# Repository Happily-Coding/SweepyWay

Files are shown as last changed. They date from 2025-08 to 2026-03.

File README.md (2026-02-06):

# SweepyWay Split Keyboard 

A truly ergonomic, begginner friendly keyboard.

<details open><summary><h2 style="display:inline-block">Photos & Outputs</h2></summary>

left side | right side
-|-
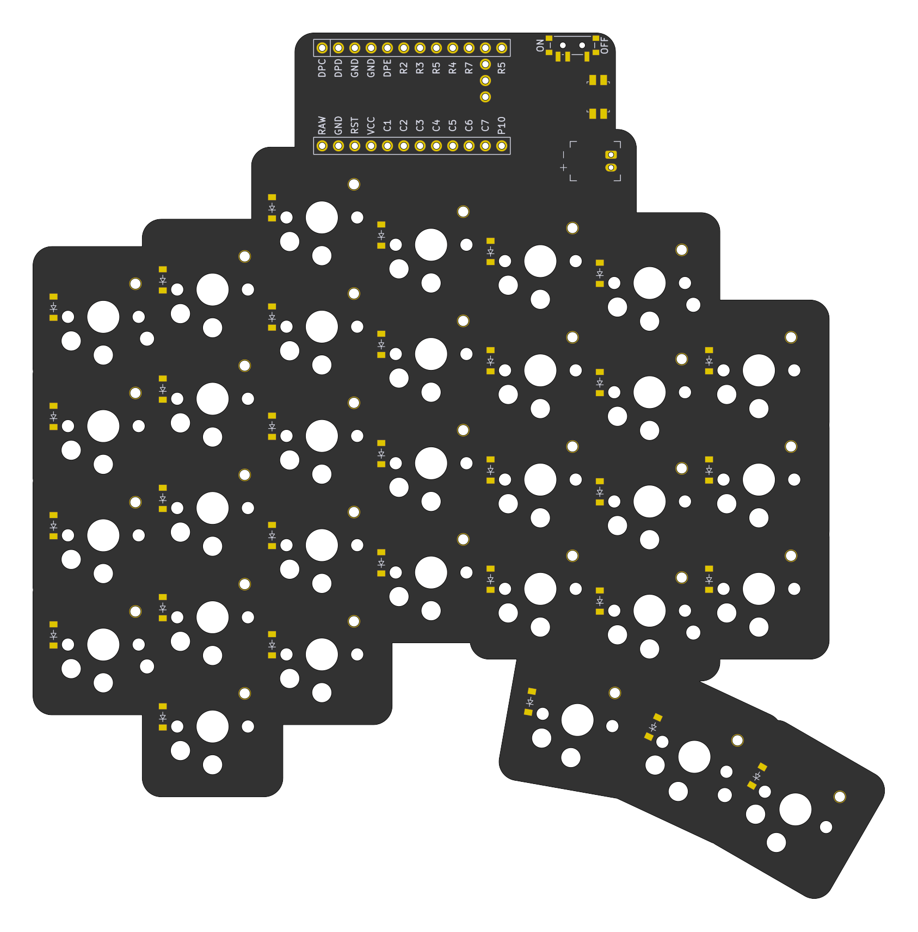
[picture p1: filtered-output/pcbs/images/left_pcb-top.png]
left
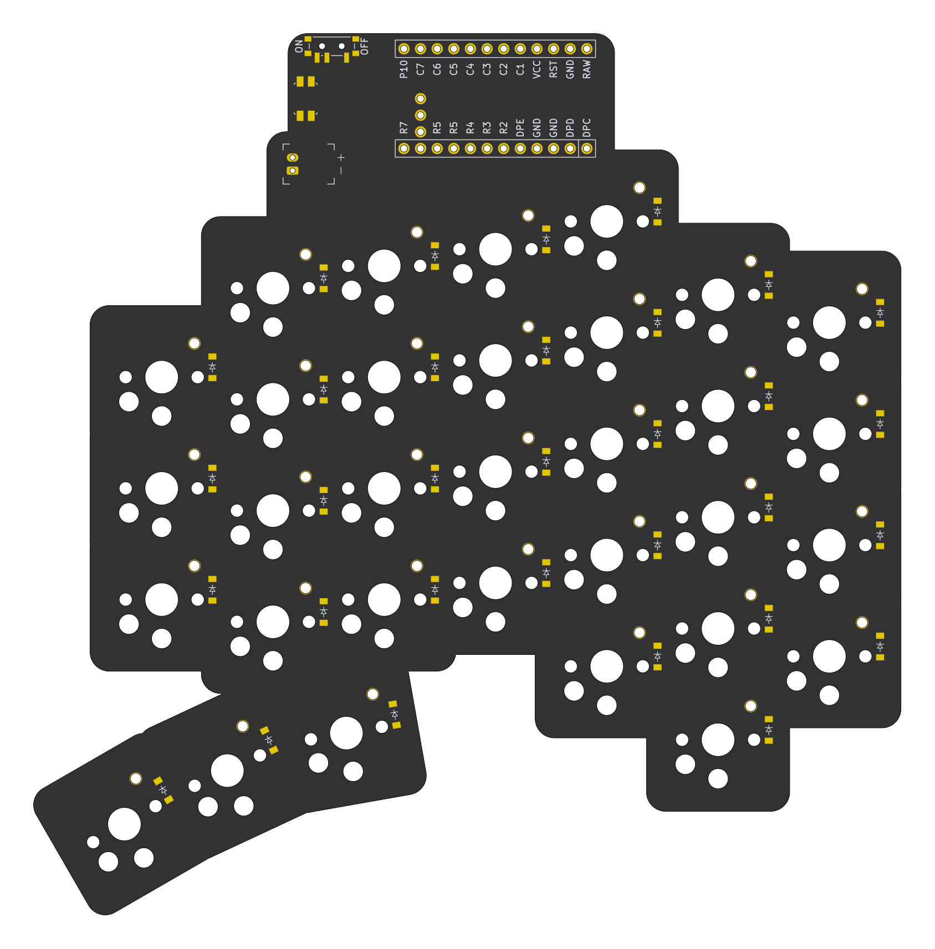
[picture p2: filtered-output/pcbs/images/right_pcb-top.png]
right
 | 

[More outputs](https://happily-coding.github.io/SweepyWay/filtered-output/) (images, pdfs, stl 3d models, etc)

<details><summary><h3 style="display:inline-block"> 3D Preview</h3></summary>

The 3D preview shows how the keyboard looks with all components in place (switches, diodes, MCU, and keycaps).

### 3D Model Files

#### Interactive 3D View (STL Format)
- [Left PCB STL](https://happily-coding.github.io/SweepyWay/filtered-output/pcbs/3d/left_pcb-3d.stl) 🎮
- [Right PCB STL](https://happily-coding.github.io/SweepyWay/filtered-output/pcbs/3d/right_pcb-3d.stl) 🎮

> 🎮 **How to View**: Click the links above, then GitHub will automatically render the STL files in an interactive 3D viewer. You can rotate, zoom, and pan using your mouse.

#### Markdown Rendering (ASCII STL)
The ASCII STL files are generated in the workflow and embedded in markdown using the ```stl code block syntax. GitHub renders these automatically when viewing the README.

> 💡 **Note**: The ASCII STL files are generated from the binary STL files in the workflow and embedded directly in this README for instant rendering.

#### STEP Files (CAD Exchange)
- [Left PCB STEP file](https://happily-coding.github.io/SweepyWay/filtered-output/pcbs/3d/left_pcb-3d.step) 🔧
- [Right PCB STEP file](https://happily-coding.github.io/SweepyWay/filtered-output/pcbs/3d/right_pcb-3d.step) 🔧

> ⚠️ **Note**: GitHub doesn't render STEP files directly. Use these for CAD software:
> - Download and open in KiCad 3D viewer, FreeCAD, Fusion 360, etc.
> - Use online STEP viewers like [3DViewer.net](https://3dviewer.net/)
> - Convert to STL format for GitHub rendering

### 3D Rendered Images

left side | right side
-|-
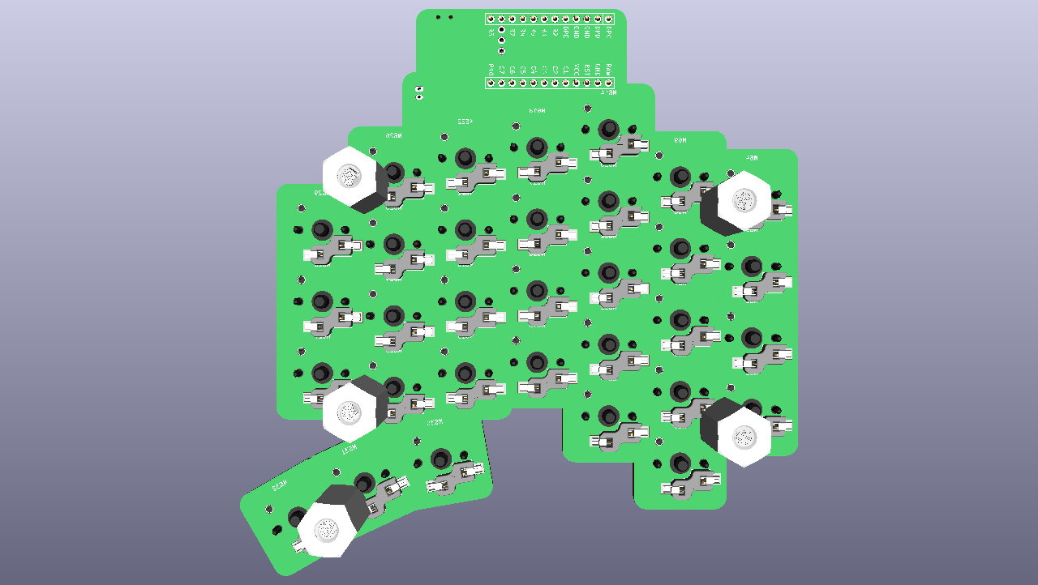
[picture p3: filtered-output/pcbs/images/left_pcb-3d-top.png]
left 3D top
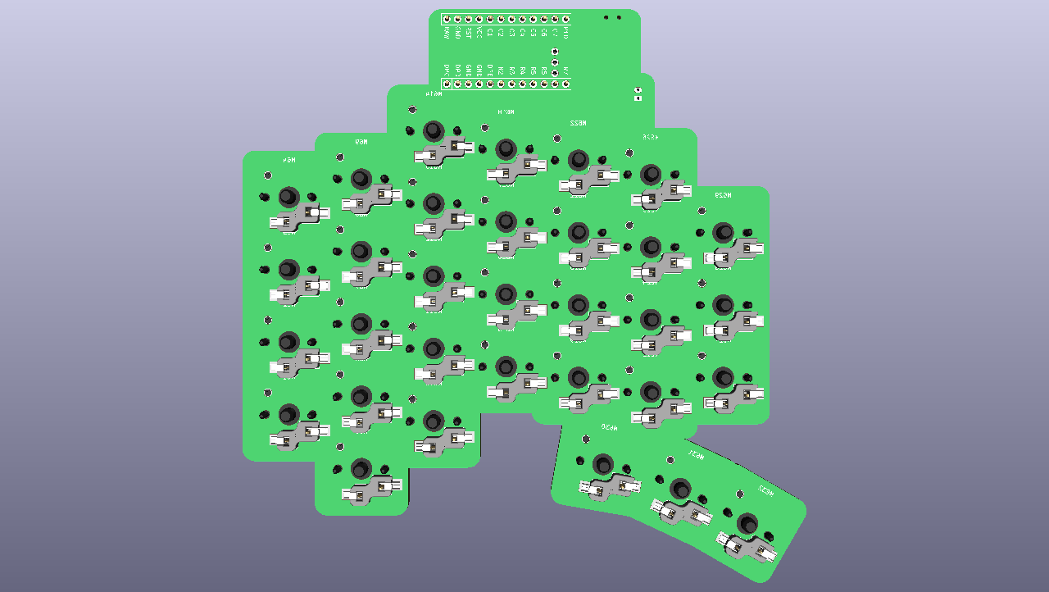
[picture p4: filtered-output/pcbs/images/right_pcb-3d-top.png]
right 3D top
 | 
left 3D bottom | right 3D bottom

### Troubleshooting Missing Components

If the 3D renders show only the PCB without components, the environment variables may not be properly set. The PCB files use `${PATH_TO_SWEEPYWAY_COMPONENT_MODELS}` but KiCad 9 also needs `KICAD9_3DMODEL_DIR`.

**Solution**: Set BOTH environment variables to the same path:
```bash
PATH_TO_SWEEPYWAY_COMPONENT_MODELS="/path/to/component_3d_models" \
KICAD9_3DMODEL_DIR="/path/to/component_3d_models" \
kibot -c kibot/3d_preview.kibot.yaml
```

**GitHub Actions**: The workflow now sets both variables to `${{ github.workspace }}/component_3d_models`

**Verification**: Check that:
1. `component_3d_models/` directory exists
2. All required STEP files are present: `Choc_V1_Hotswap.step`, `Choc_V1_Switch.step`, `Choc_V1_Keycap_MBK_White_1u.step`, etc.
3. The Docker container has access to the models directory

</details>

<details><summary><h3 style="display:inline-block"> Output details</h2></summary>
- Cases contains 3d models (not only of the case), l_cover is the plate that holds the switches firmly in place, and houses the controller and battery, protecting them
<!-- 
?v=1 was used to force the update of the cache from github (it could have been any parameter)
![left bottom](https://happily-coding.github.io/SweepyWay/images/left_pcb-bottom.png) | ![right bottom](https://happily-coding.github.io/SweepyWay/images/right_pcb-bottom.png)
-->
</details>

<details open><summary><h2 style="display:inline-block">Features</span></summary> 

* **Beginner friendly**
  * Available pdfs, so you can print the layout and see how it feels
  * Abundant keys, but in non disruptive places.
  * No soldering required (WIP)
* **Truly ergonomic**
  * Aggressive column stagger, like Ferris Sweep, to match how fingers are staggered.
  * Choc V1 keys
    * Very low actuation force switches available (example: nocturnal)
    * Low profile (seamless use without handrest, easier to adjust height without an adjustable desk)
    * ChocV1 spacing (reach the outer columns with less over-stretching)
  * Tenting, negative tilting, adjustable height and hand rest solutions (WIP)
* **Energy efficient**
  * [Nice!nano](https://nicekeyboards.com/nice-nano) optimised, but any promicro should work (bottom up) 
  <!-- * [Nice!view](https://nicekeyboards.com/nice-view) support Not tested, probably requires small modifications --> 
  * No leds
* **Accident prepared** 
  * Controller far away from accidental splash zones,
  * Power switch for transport
  * No metal plates to help prevent static discharge from friying the keyboard
  * Hotswappable battery, switches, keycaps, controller, and case. Replace anything that breaks or you dislike.
    * You can even remove the components and use them with a different pcb.
* **Easy to modify** (Declarative design done via yaml)
  * Layout is declared using [Ergogen](https://github.com/mrzealot/ergogen/). 
  * Uses Ergogen to translate YAML to a KiCad PCB and plate files for FR-4 fab or laser cutting
  * Uses Ergogen to output jscad files for the case, and openjscad to convert them to stl.
  * Uses [kicad-automation-scripts](https://github.com/productize/kicad-automation-scripts) and [FreeRouting](https://github.com/freerouting/freerouting) to **automatically route the traces on the PCB**
  * Uses [KiKit](https://github.com/yaqwsx/KiKit) to render PCB previews and production-ready **Gerber files**
  * Uses [Trimesh](https://github.com/mikedh/trimesh/tree/main) to parametrically create a palm rest for the keyboard shape.
  * Uses Kibot to produce jlpcb pos files and BOM so you can order your pcb assembled and not have to solder. (WIP) 
  * Compatible with [no solder spring headers](https://typeractive.xyz/products/no-solder-spring-headers) 

<details><summary><h2 style="display:inline-block"> Work in progress. TODO List</h2></summary>

- perfect top case, and replicate for right side
  - the controller area is delicate, we need to only increase height on the part that the controller and maybe the jsph and reset switch are, since otherwise they wont fit with the plate cutting into them
  - We need to keep the reset butotn exposed to the outside if we want to be able to use the keyboard flash with the cover on (which may be important for typing)
- add the battery and microcontroller 3d model to check there are no issues
- add a lengua in the wall of the case below the top plate to en sure no drainage on the corners?
- Add parametric tenting legs.
- Add spacing between case wall and pcb (add some more padding in addition to the wall thickness)
- Finish making hand rest parametric and integrate it into the pipeline
- Fix the additional outline to cover the controller
- make sure the bom & pos are outputed correctly and ideally automated
- Nice haves:
  - Make base tilting and tenting compatible and or adjustable height
  - add water draining holes
  - Add a piece of plastic that goes inward from the top of the border and fits in it to cover the pcb
  - add leds and spacing for a big batery in the tenting solution
  - add other controller types
  - improve controller pin assignment for better routing
  - Add headers soldering from jlpcb
  - add a tenting system with space for a larger batery or make space for a larger batery in the palm rest, so you can reasonably use the keyboard with rgb.
  - Add row staggered variants that are space efficient.
  - Make sure the keyboard is correctly produced with mbk spacing, and mx spacing.
  - Add the ability to customize keycap spacing for the outer columns and rows
</details>

<details><summary><h2 style="display:inline-block"> How to modify it</h2></summary>

### Setup
If you would like to modify this:
* fork it
* clone it locally with celoide submodule git clone --recurse-submodules https://github.com/Happily-Coding/SweepyWay.git
* change `ergogen/config.yaml` to your liking
* to test it locally if you have node, you can run npm npm i -g ergogen or just npm install from the directory of the repo.
* to be able to view the 3d models in kicad you need go to the top menu -> preferences -> path and add the value for PATH_TO_SWEEPYWAY_COMPONENT_MODELS, which should be the location of your 3d models folder for example C:\Users\YourName\KeyboardDesign\SweepyWay\component_3d_models. Then, after opening kicad , you can open the 3d viewer in the toolbar (or using alt 3).
* to be able to open individual step or stl files, i find [this page](https://3dviewer.net/index.html) comfortable
* to understand what each definition in ergogen ends up creating open the link to the repo [here ](https://ergogen.xyz/)
* reactivate github workflows
* reactivate github pages at https://github.com/your-name/your-repo/settings/pages, choose github actions instead of a branch
* push your changes; the `build.yml` GitHub Workflows(https://github.com/your-name/your-repo/actions) will pick it up, autoroute and generate Gerbers, all in a zip file, and then deploy it to github pages(https://your-name.github.io/your-repo/).
* or:
  * make sure to have Docker CLI and NodeJS installed
  * run `make setup clean all`
  * check the `output` folder for KiCad PCBs and Gerbers
* you can find the latest build artifacts [here](https://happily-coding.github.io/SweepyWay/)

See the [workflow](.github/workflows/build.yml) or the [Makefile](Makefile) for more details.

### Quickly previewing the pcb before pushing
Open the project, open a terminal, run ```cd ergogen``` and ```ergogen .```

### Quickly previewing the case and other jscad files before pushing
Open [neorama openjscad](https://neorama.de/) , and drag the jscad file to the button, you can pan and move using right click or shift rightclick.

### Quickly previewing the palmrest before pushing
- Install uv ```pip install uv``` and run uv sync to generate your virtual environment (only once)
- Run ergogen to produce the outlines.
- ```uv run palmrest_and_tenting_creation/create_palmrest.py```

<!-- 
### Add more keys in places that don't interfere with the controller
Add elements to the row or column matrix, and map them (WIP, TODO explain with more detail)

### Use other controllers

### Use mx switches / chocv2 switches

### Use other battery/reset switches/ footprints
See this examples: 
https://github.com/jsbursik/Janus-Keyboard mx nice nano reversible with custom footprints
https://github.com/tarneaux/triboard xiao controller choc spaced reversible with battery polygon!
https://github.com/Henkru/novum mx with jlpcb target, middle layer for stability, and awesome background art
https://github.com/Musab-Hassan/aurora_keyboard very detailed, and well organized mx example
https://github.com/soundmonster/samoklava/tree/main
https://github.com/christianselig/caldera-keyboard/blob/main/ergogen/config.yaml
https://github.com/jusdisgi/splaveferris/blob/main/ergogen/config.yaml (choc v1, smd) <-- reference for mirrored
https://github.com/jusdisgi/biggie-splays/blob/main/biggie-splays_choc_v1/config.yaml mirror matrix
https://pastebin.com/JzsmATYZ celoide reversible (obtianed from atreus/absolem discord) https://cdn.discordapp.com/attachments/759825860617437204/1376609916986327150/pleiades.yaml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
Complex case, and mounting example with celodie footpritns https://github.com/MalusKnight/SplitMax-Ergogen/blob/main/config.yaml and oleds
https://github.com/Nuclear-Squid/Quacken/blob/main/config.yaml [ro micro non celoide]
https://peterlyons.com/problog/2024/05/kipra-keyboard/ how to load an ergogen otuput to freecad 
https://github.com/johnlamb/LambBT/blob/main/ergogen/config.yaml case, m2 screwes, etc 
https://github.com/AtomicJon/jonkey/blob/main/jonkey-v2.yml other celoide footprints usage
https://github.com/scipioni/clavis alternative stup for auto routing 
#asym in theory can be used in outlines to get only mirrored or only normal points https://docs.ergogen.xyz/outlines/
-->
</details>

<details><summary><h2 style="display:inline-block"> Credits</h2></summary>

- [mxooaar](https://www.reddit.com/r/ErgoMechKeyboards/comments/1lanvon/comment/mxooaar/) for peaking my interest in actually building my idea for a keyboard
- [christianselig caldera keyboard](https://github.com/christianselig/caldera-keyboard) for showing that creating a custom keyboard is reasonably easy
- [Ergogen](https://github.com/ergogen/ergogen) for the awesome tool for building most of the keyboard
- [Soundmonster Samaklova Keyboard](https://github.com/soundmonster/samoklava/tree/main) for automatic electronic routing
- [tbaumann typematrix](https://github.com/tbaumann/typematrix_split_new/tree/main/ergogen) for automatic documentation, and example of how to use celoide ergonomic footprints
- [Celoide](https://github.com/ceoloide/ergogen-footprints) for the library of additional ergogen footprints for more parts and the awesome discord.
- [alakuu/skree](https://www.reddit.com/user/alakuu/) for taking the time to answer questions about pcb assembly services
- [Choco-rain](https://www.reddit.com/r/MechanicalKeyboards/comments/qanrr8/corne_with_3d_printed_cases_wrist_rests_and_plates/) for palmrest inspiration
</details>

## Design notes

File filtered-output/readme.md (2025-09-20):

Where create_palmrest produces its stl if ran locally.

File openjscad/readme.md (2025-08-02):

# Intro
The idea of using openjscad cli is to be able to convert openjscad files to stls.
This file lists the steps for local testing

# Build the image
- Build an image you can the run to perform the conversions
  - tag it as openjscad-cli so it's easily callable
  - Use the dockerfile located in openjscad
```
docker build -t openjscad-cli openjscad
```

# Run the image 
Run the image to convert all files in ergogen\output\cases to .stl

From a powershell cli at the project root:
```
docker run -it -v "${PWD}\ergogen\output\cases:/designs" openjscad-cli bash -c convert-all.sh
```

- -it: Keeps it interactive so you see output/errors
- -v "${PWD}\ergogen\output\cases:/designs" Mounts your local designs directory into the container
- openjscad-cli: The image you built and tagged
- overrides the entry point of the node image, instead executing the convert all script which on the workdir iterates through all the jscad files and outputs the stls

# Pcbway vs jlpcb vs seedfusion
Seedfusion is cheap for the microcontroller, but the assembly service is a bit expensive, and the 3d printing price is just insane

Pcbway could not autoprice my model, maybe try with an account since jlpcb didnt either without it
https://www.pcbway.com/rapid-prototyping/manufacture/?type=2&reffercode=TOP

JKOCB oyede srcear seeds studio xio ble pero sale 13.5o 12 usd de acuerdo a la cantidad. y no se si incluy shipping eso.
https://jlcpcb.com/user-center/smtPrivateLibrary/orderParts/?_t=1753498304483

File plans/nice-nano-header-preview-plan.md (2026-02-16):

# Nice!Nano Header Preview Footprint Plan

## Overview

Create a virtual footprint for displaying pin headers on the nice!nano controller in fabrication previews, POS files, and BOM - without adding any actual holes or pads to the PCB.

## Requirements

1. **Virtual Footprint**: No holes, pads, or silkscreen added to PCB
2. **3D Model**: Display header in 3D preview
3. **BOM Entry**: Include in bill of materials
4. **POS File Entry**: Include in pick-and-place file
5. **Two Headers**: One for left side, one for right side of nice!nano

## Technical Details

### Nice!Nano Dimensions (from mcu_nice_nano.js)

- Socket hole positions: X = -7.62 (left) and X = 7.62 (right)
- Row spacing: 2.54mm (standard pin header pitch)
- Number of pins per side: 12
- Y range: -12.7 to 15.24 (12 rows × 2.54mm)

### Available 3D Model

- `PinHeader_1x12_P2.54mm_Vertical.step` - Single row 12-pin vertical header
- Located in: `${PATH_TO_SWEEPYWAY_COMPONENT_MODELS}/`

### Header Positioning

The nice!nano in config.yaml is:
- Placed at `ref: mcu` 
- Rotated 90 degrees
- Has `reverse_mount: true` (MCU faces PCB)

For headers:
- Left header: positioned at the left pin row border
- Right header: positioned at the right pin row border
- Both headers should have the same rotation as the nice!nano (90 degrees)

## Implementation Plan

### Step 1: Create `header-preview_nano.js` Footprint

Create a new footprint file at:
```
ergogen/footprints/ceoloide/header-preview_nano.js
```

**Parameters:**
- `designator`: 'H' (Header)
- `side`: 'F' or 'B' (default: 'F')
- `include_silkscreen`: boolean (default: false)
- `pin_count`: number of pins (default: 12)
- `model_filename`: path to 3D model
- `model_xyz_offset`: [x, y, z] offset for 3D model positioning
- `model_xyz_rotation`: [x, y, z] rotation for 3D model
- `model_xyz_scale`: [x, y, z] scale for 3D model
- `supplier_link`: URL for BOM
- `manufacturer_part_number`: Part number for BOM
- `do_not_populate`: 'DNP' flag

**Key Features:**
- Uses `(attr exclude_from_pos_files exclude_from_bom)` is NOT set (we want it in POS/BOM)
- Or better: uses `(attr allow_soldermask_bridges)` like other preview footprints
- Includes 3D model reference
- Includes BOM properties

### Step 2: Add to config.yaml

Add two header preview entries in the `left_pcb` footprints section:

```yaml
# Left side header preview
header_left:
  what: ceoloide/header-preview_nano
  where:
    ref: mcu
  params:
    side: 'B'  # Same side as the nice_nano
    model_filename: "${PATH_TO_SWEEPYWAY_COMPONENT_MODELS}/PinHeader_1x12_P2.54mm_Vertical.step"
    model_xyz_offset: [-7.62, 0, 0]  # Offset to left pin row
    model_xyz_rotation: [0, 0, 0]  # Adjust for rotation
    supplier_link: 'https://www.digikey.com/en/products/detail/sullins-connector-solutions/PPTC121LFMS-RC/810154'
    manufacturer_part_number: 'PPTC121LFMS-RC'
    do_not_populate: 'DNP'

# Right side header preview  
header_right:
  what: ceoloide/header-preview_nano
  where:
    ref: mcu
  params:
    side: 'B'
    model_filename: "${PATH_TO_SWEEPYWAY_COMPONENT_MODELS}/PinHeader_1x12_P2.54mm_Vertical.step"
    model_xyz_offset: [7.62, 0, 0]  # Offset to right pin row
    model_xyz_rotation: [0, 0, 0]
    supplier_link: 'https://www.digikey.com/en/products/detail/sullins-connector-solutions/PPTC121LFMS-RC/810154'
    manufacturer_part_number: 'PPTC121LFMS-RC'
    do_not_populate: 'DNP'
```

### Step 3: Handle Rotation

The nice!nano is rotated 90 degrees in the config. The headers need to be positioned correctly:

- When MCU is rotated 90°, the X-axis becomes Y-axis and vice versa
- Headers should be placed at the correct offset relative to the MCU orientation
- The 3D model rotation may need adjustment to align properly

### Step 4: Duplicate for Right PCB

Add similar entries for `right_pcb` using `ref: mirror_mcu`.

## File Structure

```
ergogen/
├── footprints/
│   └── ceoloide/
│       ├── header-preview_nano.js  (NEW)
│       ├── standoff-preview.js     (reference)
│       └── hs-socket-fab-preview_choc_v1_v2.js  (reference)
└── config.yaml                      (MODIFY)
```

## Testing

1. Run ergogen to generate PCB files
2. Open in KiCad and verify:
   - Headers appear in 3D viewer
   - Headers are positioned correctly on nice!nano borders
   - Headers appear in BOM export
   - Headers appear in POS file

## Notes

- The `do_not_populate: 'DNP'` flag indicates these should not be auto-placed by the manufacturer
- Headers are typically hand-soldered after the MCU is installed
- The Z-offset may need adjustment based on actual header height

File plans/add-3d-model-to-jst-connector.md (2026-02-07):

# Add 3D Model Support to battery_connector_jst_ph_2 Footprint

## Overview

This plan outlines the steps to add 3D model support to the [`battery_connector_jst_ph_2.js`](../ergogen/footprints/ceoloide/battery_connector_jst_ph_2.js) footprint, following the same pattern used in other footprints like [`diode_tht_sod123.js`](../ergogen/footprints/ceoloide/diode_tht_sod123.js) and [`switch_choc_v1_v2.js`](../ergogen/footprints/ceoloide/switch_choc_v1_v2.js).

## Current Status

- **Footprint File**: [`ergogen/footprints/ceoloide/battery_connector_jst_ph_2.js`](../ergogen/footprints/ceoloide/battery_connector_jst_ph_2.js)
- **3D Model Support**: ❌ No - Not Configured
- **Available 3D Models**: ✅ Yes - Files already exist in [`component_3d_models/`](../component_3d_models/):
  - `JSTPH2 S2B-PH-K-S(LF)(SN).STEP`
  - `JSTPH2 S2B-PH-K-S(LF)(SN).wrl`

## Pattern Analysis

Based on analysis of other footprints, the 3D model implementation follows this pattern:

### 1. Parameters Section
Add four parameters to the `params` object:
- `<component>_3dmodel_filename`: Path to STEP/WRL file (default: '')
- `<component>_3dmodel_xyz_offset`: [x, y, z] offset in mm (default: [0, 0, 0])
- `<component>_3dmodel_xyz_scale`: [x, y, z] scale factors (default: [1, 1, 1])
- `<component>_3dmodel_xyz_rotation`: [x, y, z] rotation in degrees (default: [0, 0, 0])

### 2. Template String
Create a template string constant that generates the KiCad 3D model entry.

### 3. Conditional Inclusion
Add a conditional check before the footprint closing parenthesis to include the 3D model only if a filename is provided.

### 4. Documentation
Add parameter documentation in the comments section.

## Implementation Steps

### Step 1: Add Parameter Documentation

Add the following documentation after line 41 (after `include_courtyard` parameter description):

```javascript
//    connector_3dmodel_filename: default is ''
//      Allows you to specify the path to a 3D model STEP or WRL file to be
//      used when rendering the PCB. Use the ${VAR_NAME} syntax to point to
//      a KiCad configured path.
//    connector_3dmodel_xyz_offset: default is [0, 0, 0]
//      xyz offset (in mm), used to adjust the position of the 3d model
//      relative the footprint.
//    connector_3dmodel_xyz_scale: default is [1, 1, 1]
//      xyz scale, used to adjust the size of the 3d model relative to its
//      original size.
//    connector_3dmodel_xyz_rotation: default is [0, 0, 0]
//      xyz rotation (in degrees), used to adjust the orientation of the 3d
//      model relative the footprint.
```

### Step 2: Add Parameters to params Object

Add the following parameters to the `params` object after line 52 (after `BAT_N` parameter):

```javascript
    connector_3dmodel_filename: '',
    connector_3dmodel_xyz_offset: [0, 0, 0],
    connector_3dmodel_xyz_scale: [1, 1, 1],
    connector_3dmodel_xyz_rotation: [0, 0, 0],
```

### Step 3: Add 3D Model Template String

Add the following template string constant after line 282 (after `reversible_traces` constant):

```javascript
    const connector_3dmodel = `
        (model ${p.connector_3dmodel_filename}
            (offset (xyz ${p.connector_3dmodel_xyz_offset[0]} ${p.connector_3dmodel_xyz_offset[1]} ${p.connector_3dmodel_xyz_offset[2]}))
            (scale (xyz ${p.connector_3dmodel_xyz_scale[0]} ${p.connector_3dmodel_xyz_scale[1]} ${p.connector_3dmodel_xyz_scale[2]}))
            (rotate (xyz ${p.connector_3dmodel_xyz_rotation[0]} ${p.connector_3dmodel_xyz_rotation[1]} ${p.connector_3dmodel_xyz_rotation[2]}))
        )
        `
```

### Step 4: Add Conditional Inclusion

Modify the code after line 325 (after `final += standard_closing;`) to add conditional inclusion:

```javascript
    final += standard_closing;
    
    if (p.connector_3dmodel_filename) {
      final += connector_3dmodel
    }
    
    if (p.reversible && p.include_traces) {
      final += reversible_traces;
    }
```

**Note**: The 3D model should be added inside the footprint before the closing parenthesis, so we need to add it BEFORE `standard_closing`, not after. Let me correct this:

### Step 4 (Corrected): Add Conditional Inclusion

Modify the code around line 325 to add conditional inclusion BEFORE `standard_closing`:

```javascript
    if (p.reversible) {
      final += reversible_pads;
    } else if (p.side == "F") {
      final += front_pads;
    } else if (p.side == "B") {
      final += back_pads;
    }
    
    if (p.connector_3dmodel_filename) {
      final += connector_3dmodel
    }
    
    final += standard_closing;
    if (p.reversible && p.include_traces) {
      final += reversible_traces;
    }
```

## Expected Result

After implementation, the footprint will support 3D models that can be configured in [`ergogen/config.yaml`](../ergogen/config.yaml) like this:

```yaml
pads_bat:
  what: ceoloide/battery_connector_jst_ph_2
  params:
    connector_3dmodel_filename: "${PATH_TO_SWEEPYWAY_COMPONENT_MODELS}/JSTPH2 S2B-PH-K-S(LF)(SN).wrl"
    connector_3dmodel_xyz_offset: [0, 0, 0]
    connector_3dmodel_xyz_scale: [1, 1, 1]
    connector_3dmodel_xyz_rotation: [0, 0, 0]
  where:
    ref: mcu
    shift: [mcu_x/2 +22, -10]
    rotate: 270
```

## Testing Checklist

After implementation:

- [ ] Verify the modified footprint file has correct syntax
- [ ] Run `ergogen .` in the `ergogen` directory to regenerate PCB files
- [ ] Open the generated KiCad files
- [ ] Use the 3D viewer (Alt+3) to verify the model appears correctly
- [ ] Check that the connector model is properly positioned and oriented
- [ ] Verify no errors in KiCad console
- [ ] Test with both STEP and WRL formats
- [ ] Test with reversible and non-reversible configurations

## Notes

1. **Parameter Naming**: Using `connector_3dmodel_*` prefix to be consistent with the component type and avoid conflicts with other parameters.

2. **Model Format**: KiCad supports both STEP (.step, .stp) and WRL (.wrl) formats. WRL is typically preferred for KiCad 3D viewer performance.

3. **Offset and Rotation**: The default values (0, 0, 0) may need adjustment based on the actual 3D model's origin and orientation. Users can fine-tune these values in their config.yaml.

4. **Reversible Footprints**: For reversible footprints, the 3D model should only appear once (not duplicated on both sides) since the component is only mounted on one side.

5. **Existing Models**: The 3D model files already exist in the project at:
   - [`component_3d_models/JSTPH2 S2B-PH-K-S(LF)(SN).STEP`](../component_3d_models/JSTPH2%20S2B-PH-K-S(LF)(SN).STEP)
   - [`component_3d_models/JSTPH2 S2B-PH-K-S(LF)(SN).wrl`](../component_3d_models/JSTPH2%20S2B-PH-K-S(LF)(SN).wrl)

## References

- Similar implementation in [`diode_tht_sod123.js`](../ergogen/footprints/ceoloide/diode_tht_sod123.js:24-36, 55-58, 102-107, 124-126)
- Similar implementation in [`switch_choc_v1_v2.js`](../ergogen/footprints/ceoloide/switch_choc_v1_v2.js:79-117, 180-191, 453-475, 535-541)
- JST PH 2.0mm connector datasheet: https://cdn.shopify.com/s/files/1/0618/5674/3655/files/JST-S2B-PH-K.pdf?v=1670451309
- 3D model source: https://www.snapeda.com/parts/S2B-PH-K-S(LF)(SN)/JST/view-part/

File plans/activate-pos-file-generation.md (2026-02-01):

# Plan: Activate POS File Generation in GitHub Actions

## Current State

### What's Already Implemented

1. **POS File Generation** (`.github/workflows/build.yaml:73-77`)
   - KiBot generates POS files using `jlpcb_pos.kibot.yaml` configuration
   - Files are output to `ergogen/output/pos/` directory
   - Separate files for front and back sides

2. **Post-Processing Script** (`kibot/fix_pos_package_name.py`)
   - Replaces footprint names with JLCPCB part numbers
   - Maps `switch_choc_v1_v2` → `CPG135001S30`
   - Already tested and working (verified in `manualboms/manualpos 2026-02-01/`)

3. **KiBot Configuration** (`kibot/jlpcb_pos.kibot.yaml`)
   - Generates ASCII format position files
   - Units in millimeters
   - Separate files for front and back
   - Only SMD components (hotswap sockets are SMD)

### What's Missing

The GitHub Actions workflow does **not**:
1. Run the post-processing script on generated POS files
2. Copy the processed POS files to `filtered-output` directory for deployment

## Required Changes

### 1. Add Post-Processing Step to Workflow

Add a new step after the POS file generation (after line 77 in `.github/workflows/build.yaml`):

```yaml
- name: Post-process POS files for JLCPCB
  run: |
    for board in left_pcb right_pcb; do
      for side in bottom top; do
        input_file="ergogen/output/pos/${board}/${board}-${side}.pos"
        if [ -f "$input_file" ]; then
          python kibot/fix_pos_package_name.py "$input_file" "${input_file}-jlcpcb.pos"
        fi
      done
    done
```

### 2. Copy Processed POS Files to filtered-output

Add a step after the post-processing step:

```yaml
- name: Copy processed POS files to filtered-output
  run: |
    mkdir -p filtered-output/pos
    for board in left_pcb right_pcb; do
      for side in bottom top; do
        if [ -f "ergogen/output/pos/${board}/${board}-${side}-jlcpcb.pos" ]; then
          cp "ergogen/output/pos/${board}/${board}-${side}-jlcpcb.pos" "filtered-output/pos/"
        fi
      done
    done
```

### 3. Update Existing "Make filtered output" Step

The existing step (lines 70-72) already copies `ergogen/output/` to `filtered-output/`, but it excludes `fp-info-cache`. We need to ensure POS files are included.

Current step:
```yaml
- name: Make filtered output (excluding fp-info-cache) 1
  run: |
    rsync -a --exclude='fp-info-cache' ergogen/output/ filtered-output/
```

This should already include POS files, but we should verify the directory structure is correct.

## Expected Output Structure

After activation, the `filtered-output/` directory will contain:

```
filtered-output/
├── pos/
│   ├── left_pcb-bottom-jlcpcb.pos
│   ├── left_pcb-top-jlcpcb.pos
│   ├── right_pcb-bottom-jlcpcb.pos
│   └── right_pcb-top-jlcpcb.pos
├── gerbers/
├── images/
└── cases/
```

## POS File Format

The processed POS files will have the format:

```
### Footprint positions - created on <timestamp> ###
### Printed by KiCad version 9.0.2
## Unit = mm, Angle = deg.
## Side : bottom
# Ref     Val       Package                 PosX       PosY       Rot  Side
S1                  CPG135001S30            35.0000  -133.0000  180.0000  bottom
S2                  CPG135001S30            35.0000  -116.0000  180.0000  bottom
...
## End
```

## Workflow Changes

Here's the complete workflow section that needs modification:

```yaml
# ... existing steps ...

- name: Run KiBot to generate jlpcb pos
  uses: ./.github/actions/kibot
  with:
    boards: left_pcb right_pcb
    config: jlpcb_pos

- name: Post-process POS files for JLCPCB
  run: |
    for board in left_pcb right_pcb; do
      for side in bottom top; do
        input_file="ergogen/output/pos/${board}/${board}-${side}.pos"
        if [ -f "$input_file" ]; then
          python kibot/fix_pos_package_name.py "$input_file" "${input_file}-jlcpcb.pos"
        fi
      done
    done

- name: Copy processed POS files to filtered-output
  run: |
    mkdir -p filtered-output/pos
    for board in left_pcb right_pcb; do
      for side in bottom top; do
        if [ -f "ergogen/output/pos/${board}/${board}-${side}-jlcpcb.pos" ]; then
          cp "ergogen/output/pos/${board}/${board}-${side}-jlcpcb.pos" "filtered-output/pos/"
        fi
      done
    done

- name: Run KiBot to generate jlpcb bom
  uses: ./.github/actions/kibot
  with:
    boards: left_pcb right_pcb
    config: jlpcb_bom

# ... rest of workflow ...
```

## Benefits

1. **Automated JLCPCB Assembly**: POS files with correct part numbers will be automatically generated
2. **No Manual Steps**: Eliminates the need to manually run the post-processing script
3. **Consistent Output**: Every build will have the same POS file format
4. **Version Control**: POS files are tracked in the build artifacts
5. **Easy Deployment**: Files are automatically deployed to GitHub Pages

## Testing

After implementing the changes:

1. Trigger a workflow run (either by pushing to main or using workflow_dispatch)
2. Check the workflow logs to ensure:
   - POS files are generated by KiBot
   - Post-processing script runs successfully
   - Files are copied to filtered-output
3. Download the build artifacts
4. Verify POS files contain `CPG135001S30` instead of `switch_choc_v1_v2`

## Notes

- The post-processing script is idempotent (can be run multiple times safely)
- If a POS file doesn't exist (e.g., no components on that side), the script will skip it gracefully
- The `-jlcpcb.pos` suffix distinguishes processed files from raw POS files
- Both raw and processed files are preserved for debugging purposes

## Related Files

- `.github/workflows/build.yaml` - Main workflow file to modify
- `kibot/jlpcb_pos.kibot.yaml` - POS file generation configuration (already complete)
- `kibot/fix_pos_package_name.py` - Post-processing script (already complete)
- `ergogen/footprints/ceoloide/switch_choc_v1_v2.js` - Switch footprint with include_in_pos_files parameter
- `ergogen/config.yaml` - Config with include_in_pos_files: true for switches

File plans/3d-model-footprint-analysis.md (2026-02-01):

# 3D Model Footprint Analysis for SweepyWay Keyboard

## Executive Summary

This document analyzes the footprint configurations for the controller, power switch, SMD diodes, reset switch, and JST PH connector in the SweepyWay keyboard project. It identifies which footprints currently support 3D models, which don't, and provides recommendations for adding 3D model support.

**Note:** Reset switch and JST PH connector 3D model implementation is deferred for now.

## Current Status Overview

### 1. Controller (Nice!Nano V2)

**Footprint File:** [`ergogen/footprints/ceoloide/mcu_nice_nano.js`](../ergogen/footprints/ceoloide/mcu_nice_nano.js)

**3D Model Support:** ✅ **YES - Already Configured**

**Parameters Available:**
- `mcu_3dmodel_filename`: Path to STEP/WRL file
- `mcu_3dmodel_xyz_offset`: [x, y, z] offset in mm
- `mcu_3dmodel_xyz_scale`: [x, y, z] scale factors
- `mcu_3dmodel_xyz_rotation`: [x, y, z] rotation in degrees

**Current Usage in config.yaml:**
```yaml
promicro:
  what: ceoloide/mcu_nice_nano
  params:
    reverse_mount: true
    include_extra_pins: true
    # Pin assignments...
```

**Status:** The footprint supports 3D models but the parameters are not currently set in [`config.yaml`](../ergogen/config.yaml:805-844).

**Available 3D Model:**
- File exists: [`component_3d_models/Nice_Nano_V2.step`](../component_3d_models/Nice_Nano_V2.step)
- Source: https://github.com/infused-kim/kb_ergogen_fp/tree/main/3d_models

**Recommendation:** ✅ **EASY TO CONFIGURE** - Add the 3D model parameters to the config.yaml file.

---

### 2. Power Switch (Alps SSSS811101)

**Footprint File:** [`ergogen/footprints/ceoloide/power_switch_smd_side.js`](../ergogen/footprints/ceoloide/power_switch_smd_side.js)

**3D Model Support:** ✅ **YES - Already Configured**

**Parameters Available:**
- `switch_3dmodel_filename`: Path to STEP/WRL file
- `switch_3dmodel_xyz_offset`: [x, y, z] offset in mm
- `switch_3dmodel_xyz_scale`: [x, y, z] scale factors
- `switch_3dmodel_xyz_rotation`: [x, y, z] rotation in degrees

**Current Usage in config.yaml:**
```yaml
power:
  what: ceoloide/power_switch_smd_side
  params:
    side: F
  adjust:
    rotate: 90
  where:
    ref: mcu
    shift: [mcu_x/2 +16, 8]
```

**Status:** The footprint supports 3D models but the parameters are not currently set in [`config.yaml`](../ergogen/config.yaml:863-873).

**Available 3D Model Sources:**
- UltraLibrarian: https://app.ultralibrarian.com/details/877b6255-2882-11e9-ab3a-0a3560a4cccc/Alps-Electric/SSSS811101
- SnapEDA: https://www.snapeda.com/parts/SSSS811101/ALPS/view-part/
- Datasheet: https://cdn.shopify.com/s/files/1/0618/5674/3655/files/ALPS-SSSS811101.pdf?v=1670451309

**Recommendation:** ✅ **EASY TO CONFIGURE** - Download a 3D model and add the parameters to config.yaml.

---

### 3. SMD Diode (SOD-123 Package - 1N4148W)

**Footprint File:** [`ergogen/footprints/ceoloide/diode_tht_sod123.js`](../ergogen/footprints/ceoloide/diode_tht_sod123.js)

**3D Model Support:** ✅ **YES - Already Configured**

**Parameters Available:**
- `diode_3dmodel_filename`: Path to STEP/WRL file
- `diode_3dmodel_xyz_offset`: [x, y, z] offset in mm
- `diode_3dmodel_xyz_scale`: [x, y, z] scale factors
- `diode_3dmodel_xyz_rotation`: [x, y, z] rotation in degrees

**Current Usage in config.yaml:**
```yaml
diode:
  what: ceoloide/diode_tht_sod123
  where:
    - leftkey
  params:
    from: "{{colrow}}"
    to: "{{row_net}}"
    side: F
    include_tht: false
    reversible: false
  adjust:
    shift: [horizontal_diode_shift,vertical_diode_shift]
    rotate: 90 + diode_rotation
```

**Status:** The footprint supports 3D models but the parameters are not currently set in [`config.yaml`](../ergogen/config.yaml:791-803).

**Available 3D Model Sources:**
- UltraLibrarian: Search for "SOD-123" or "1N4148W"
- SnapEDA: https://www.snapeda.com/ (search for 1N4148W)
- Datasheet: https://cdn.shopify.com/s/files/1/0618/5674/3655/files/Semtech-1N4148W.pdf?v=1670451309
- KiCad library: Many KiCad installations include SOD-123 3D models in the default libraries

**Recommendation:** ✅ **EASY TO CONFIGURE** - Download a 3D model and add the parameters to config.yaml.

**Note:** Since there are multiple diodes in the keyboard (one per key), adding 3D models for all of them may significantly increase the file size and rendering time. Consider whether you need 3D models for all diodes or just a representative sample.

---

### 4. Reset Switch (Panasonic EVQ-PU[A|C|J|L]02K) ⏸️ **DEFERRED**

**Footprint File:** [`ergogen/footprints/ceoloide/reset_switch_smd_side.js`](../ergogen/footprints/ceoloide/reset_switch_smd_side.js)

**3D Model Support:** ❌ **NO - Not Configured**

**Parameters Available:** None

**Current Usage in config.yaml:**
```yaml
reset:
  what: ceoloide/reset_switch_smd_side
  params:
    side: F
    from: GND
    to: RST
  adjust:
    rotate: 270
  where:
    ref: mcu
    shift: [mcu_x/2 +18 +2, -0]
```

**Status:** The footprint does NOT have 3D model parameters. The code would need to be modified.

**Available 3D Model Sources:**
- SnapEDA: https://www.snapeda.com/parts/EVQ-PUC02K/Panasonic/view-part/
- UltraLibrarian: https://app.ultralibrarian.com/details/a0479524-2b3d-11ea-a124-0ad2c9526b44/Panasonic/EVQ-PUJ02K
- Datasheet: https://cdn.shopify.com/s/files/1/0618/5674/3655/files/PANASONIC-EVQPUC02K.pdf?v=1670451309

**Recommendation:** ⚠️ **REQUIRES CODE MODIFICATION** - Add 3D model parameters to the footprint file following the pattern used in power_switch_smd_side.js.

---

### 5. JST PH 2-Pin Battery Connector ⏸️ **DEFERRED**

**Footprint File:** [`ergogen/footprints/ceoloide/battery_connector_jst_ph_2.js`](../ergogen/footprints/ceoloide/battery_connector_jst_ph_2.js)

**3D Model Support:** ❌ **NO - Not Configured**

**Parameters Available:** None

**Current Usage in config.yaml:**
```yaml
pads_bat:
  what: ceoloide/battery_connector_jst_ph_2
  params:
  where:
    ref: mcu
    shift: [mcu_x/2 +22, -10]
    rotate: 270
```

**Status:** The footprint does NOT have 3D model parameters. The code would need to be modified.

**Available 3D Model Sources:**
- JST official website may have CAD models
- SnapEDA typically has JST connector models
- Datasheet: https://cdn.shopify.com/s/files/1/0618/5674/3655/files/JST-S2B-PH-K.pdf?v=1670451309

**Recommendation:** ⚠️ **REQUIRES CODE MODIFICATION** - Add 3D model parameters to the footprint file.

---

## Summary Table

| Component | Footprint Has 3D Support? | Configured in YAML? | Action Required | Priority |
|---|---|---|---|---|
| Nice!Nano V2 Controller | ✅ Yes | ❌ No | Add parameters to config.yaml | High |
| Power Switch (SSSS811101) | ✅ Yes | ❌ No | Add parameters to config.yaml | High |
| SMD Diode (SOD-123) | ✅ Yes | ❌ No | Add parameters to config.yaml | Medium |
| Reset Switch (EVQ-PU02K) | ❌ No | N/A | Modify footprint file | ⏸️ Deferred |
| JST PH Connector | ❌ No | N/A | Modify footprint file | ⏸️ Deferred |

---

## Implementation Plan

### Phase 1: Easy Wins (No Code Changes) - Current Focus

These components have 3D model support built into their footprints and only need configuration in config.yaml.

#### 1.1 Configure Nice!Nano V2 3D Model

Add to [`config.yaml`](../ergogen/config.yaml:805-844) in the `promicro` section:

```yaml
promicro:
  what: ceoloide/mcu_nice_nano
  params:
    reverse_mount: true
    include_extra_pins: true
    mcu_3dmodel_filename: "${PATH_TO_SWEEPYWAY_COMPONENT_MODELS}/Nice_Nano_V2.step"
    mcu_3dmodel_xyz_offset: [0, 0, 0]
    mcu_3dmodel_xyz_scale: [1, 1, 1]
    mcu_3dmodel_xyz_rotation: [0, 0, 0]
    # ... rest of pin assignments
```

#### 1.2 Configure Power Switch 3D Model

First, download a 3D model from one of the sources above and save it to [`component_3d_models/`](../component_3d_models/).

Then add to [`config.yaml`](../ergogen/config.yaml:863-873) in the `power` section:

```yaml
power:
  what: ceoloide/power_switch_smd_side
  params:
    side: F
    switch_3dmodel_filename: "${PATH_TO_SWEEPYWAY_COMPONENT_MODELS}/Alps_SSSS811101.step"
    switch_3dmodel_xyz_offset: [0, 0, 0]
    switch_3dmodel_xyz_scale: [1, 1, 1]
    switch_3dmodel_xyz_rotation: [0, 0, 0]
  adjust:
    rotate: 90
  where:
    ref: mcu
    shift: [mcu_x/2 +16, 8]
```

#### 1.3 Configure SMD Diode 3D Model

First, download a 3D model from one of the sources above and save it to [`component_3d_models/`](../component_3d_models/).

Then add to [`config.yaml`](../ergogen/config.yaml:791-803) in the `diode` section:

```yaml
diode:
  what: ceoloide/diode_tht_sod123
  where:
    - leftkey
  params:
    from: "{{colrow}}"
    to: "{{row_net}}"
    side: F
    include_tht: false
    reversible: false
    diode_3dmodel_filename: "${PATH_TO_SWEEPYWAY_COMPONENT_MODELS}/SOD123_1N4148W.step"
    diode_3dmodel_xyz_offset: [0, 0, 0]
    diode_3dmodel_xyz_scale: [1, 1, 1]
    diode_3dmodel_xyz_rotation: [0, 0, 0]
  adjust:
    shift: [horizontal_diode_shift,vertical_diode_shift]
    rotate: 90 + diode_rotation
```

**Important Note:** The SweepyWay keyboard has multiple diodes (one per key). Adding 3D models for all diodes will:
- Increase the KiCad file size significantly
- Slow down 3D rendering in KiCad
- May not provide much additional value since diodes are small and uniform

**Recommendation:** Consider starting with just a few diodes to test, or skip diode 3D models entirely if they don't add significant value to your design verification process.

### Phase 2: Deferred - Code Modifications Required ⏸️

The following components require code modifications to their footprint files. Implementation is deferred for now.

#### 2.1 Add 3D Model Support to Reset Switch Footprint

Modify [`ergogen/footprints/ceoloide/reset_switch_smd_side.js`](../ergogen/footprints/ceoloide/reset_switch_smd_side.js):

1. Add parameters to the `params` object (around line 34):
```javascript
module.exports = {
  params: {
    designator: 'RST',
    side: 'F',
    reversible: false,
    include_bosses: false,
    include_silkscreen: true,
    include_courtyard: false,
    switch_3dmodel_filename: '',
    switch_3dmodel_xyz_offset: [0, 0, 0],
    switch_3dmodel_xyz_rotation: [0, 0, 0],
    switch_3dmodel_xyz_scale: [1, 1, 1],
    from: { type: 'net', value: 'GND' },
    to: { type: 'net', value: 'RST' },
  },
```

2. Add 3D model generation code before the `common_end` (around line 107):
```javascript
    const switch_3dmodel = `
    (model ${p.switch_3dmodel_filename}
      (offset (xyz ${p.switch_3dmodel_xyz_offset[0]} ${p.switch_3dmodel_xyz_offset[1]} ${p.switch_3dmodel_xyz_offset[2]}))
      (scale (xyz ${p.switch_3dmodel_xyz_scale[0]} ${p.switch_3dmodel_xyz_scale[1]} ${p.switch_3dmodel_xyz_scale[2]}))
      (rotate (xyz ${p.switch_3dmodel_xyz_rotation[0]} ${p.switch_3dmodel_xyz_rotation[1]} ${p.switch_3dmodel_xyz_rotation[2]}))
    )
    `
```

3. Add conditional inclusion before `common_end` (around line 132):
```javascript
    if (p.switch_3dmodel_filename) {
      final += switch_3dmodel
    }

    final += common_end;
```

4. Update config.yaml to use the new parameters (similar to power switch).

#### 2.2 Add 3D Model Support to JST PH Connector Footprint

Modify [`ergogen/footprints/ceoloide/battery_connector_jst_ph_2.js`](../ergogen/footprints/ceoloide/battery_connector_jst_ph_2.js):

1. Add parameters to the `params` object (around line 43):
```javascript
module.exports = {
  params: {
    designator: 'JST',
    side: 'F',
    reversible: false,
    include_traces: true,
    trace_width: 0.250,
    include_silkscreen: true,
    include_fabrication: true,
    include_courtyard: true,
    connector_3dmodel_filename: '',
    connector_3dmodel_xyz_offset: [0, 0, 0],
    connector_3dmodel_xyz_rotation: [0, 0, 0],
    connector_3dmodel_xyz_scale: [1, 1, 1],
    BAT_P: { type: 'net', value: 'BAT_P' },
    BAT_N: { type: 'net', value: 'GND' },
  },
```

2. Add 3D model generation code before `standard_closing` (around line 283):
```javascript
    const connector_3dmodel = `
    (model ${p.connector_3dmodel_filename}
      (offset (xyz ${p.connector_3dmodel_xyz_offset[0]} ${p.connector_3dmodel_xyz_offset[1]} ${p.connector_3dmodel_xyz_offset[2]}))
      (scale (xyz ${p.connector_3dmodel_xyz_scale[0]} ${p.connector_3dmodel_xyz_scale[1]} ${p.connector_3dmodel_xyz_scale[2]}))
      (rotate (xyz ${p.connector_3dmodel_xyz_rotation[0]} ${p.connector_3dmodel_xyz_rotation[1]} ${p.connector_3dmodel_xyz_rotation[2]}))
    )
    `
```

3. Add conditional inclusion before `standard_closing` (around line 325):
```javascript
    final += standard_closing;
    if (p.connector_3dmodel_filename) {
      final += connector_3dmodel
    }
    if (p.reversible && p.include_traces) {
      final += reversible_traces;
    }
```

4. Update config.yaml to use the new parameters.

---

## Additional Resources

### 3D Model Sources

1. **infused-kim's 3D Models** (Already used in project):
   - https://github.com/infused-kim/kb_ergogen_fp/tree/main/3d_models
   - Contains: Choc switches, keycaps, Nice!Nano V2, and more

2. **GrabCAD**:
   - https://grabcad.com/library/nice-nano-v2-1
   - https://grabcad.com/library/kailh-low-profile-mechanical-keyboard-switch-1

3. **UltraLibrarian**:
   - Alps SSSS811101: https://app.ultralibrarian.com/details/877b6255-2882-11e9-ab3a-0a3560a4cccc
   - Panasonic EVQ-PUJ02K: https://app.ultralibrarian.com/details/a0479524-2b3d-11ea-a124-0ad2c9526b44

4. **SnapEDA**:
   - Alps SSSS811101: https://www.snapeda.com/parts/SSSS811101/ALPS/view-part/
   - Panasonic EVQ-PUC02K: https://www.snapeda.com/parts/EVQ-PUC02K/Panasonic/view-part/

5. **Printables** (For printable dummy models):
   - Choc V1/V2 dummies: https://www.printables.com/model/716753-kaliah-choc-v1-v2-dummy/files

### Celoide Footprints Documentation

- https://github.com/ceoloide/ergogen-footprints
- The footprints already follow a consistent pattern for 3D model support

---

## Performance Considerations for Diode 3D Models

The SweepyWay keyboard uses a significant number of diodes (one per key). Before adding 3D models to all diodes, consider:

**Pros:**
- More complete visualization of the board
- Can verify diode orientation and placement
- Useful for documentation and presentations

**Cons:**
- **File Size Impact:** Each 3D model adds to the KiCad file size (typically 50-200KB per model)
- **Rendering Performance:** With 30+ diodes, 3D viewer may become sluggish
- **Limited Value:** Diodes are small, uniform components that don't typically cause clearance issues
- **Build Time:** Ergogen generation may take longer

**Recommendations:**
1. Start without diode 3D models to establish baseline performance
2. If needed, add 3D models to only a few representative diodes for visualization
3. Consider using simplified/low-poly diode models if performance becomes an issue
4. Test with your specific hardware to determine if the performance impact is acceptable

---

## Testing Checklist

After implementing Phase 1 3D models:

- [ ] Run `ergogen .` in the `ergogen` directory to regenerate PCB files
- [ ] Open the generated KiCad files
- [ ] Use the 3D viewer (Alt+3) to verify models appear correctly
- [ ] Check that controller model is properly positioned and oriented
- [ ] Check that power switch model is properly positioned and oriented
- [ ] If diode 3D models added: verify they don't cause performance issues
- [ ] Verify no collisions between components
- [ ] Test with both left and right PCB configurations
- [ ] Ensure the case design accommodates the 3D models
- [ ] Check file size impact (compare before/after)

---

## Notes

1. **Environment Variable**: Remember to set `PATH_TO_SWEEPYWAY_COMPONENT_MODELS` in KiCad preferences as mentioned in the README.

2. **Model Format**: KiCad supports STEP (.step, .stp), WRL (.wrl), and GLTF (.glb, .gltf) formats. STEP is preferred for mechanical parts.

3. **Model Quality**: Ensure downloaded models are of reasonable quality and not overly complex (too many polygons can slow down KiCad).

4. **Offset and Rotation**: You may need to adjust the offset and rotation values to align models correctly with the footprint. The footprint origin is typically at the component's reference point.

5. **Reversible Footprints**: For reversible footprints, the 3D model should only appear on one side (the side where the component is mounted).

---

## Conclusion

The SweepyWay keyboard project has good 3D model support infrastructure in place. Three components (controller, power switch, and SMD diodes) can be configured immediately without code changes. Two components (reset switch and JST connector) would require minor modifications to their footprint files but implementation is deferred for now.

### Immediate Actions (Phase 1)

1. **Nice!Nano V2 Controller** - Add 3D model parameters to config.yaml (model file already exists)
2. **Power Switch** - Download 3D model and add parameters to config.yaml
3. **SMD Diodes** - Optional: Download 3D model and add parameters to config.yaml (consider performance impact)

### Deferred Actions (Phase 2)

4. **Reset Switch** - Requires footprint file modification (deferred)
5. **JST PH Connector** - Requires footprint file modification (deferred)

Implementing the Phase 1 3D models will significantly improve the ability to visualize and verify the design before manufacturing, helping to catch potential issues early in the development process. The deferred components can be addressed later if needed for more detailed design verification.

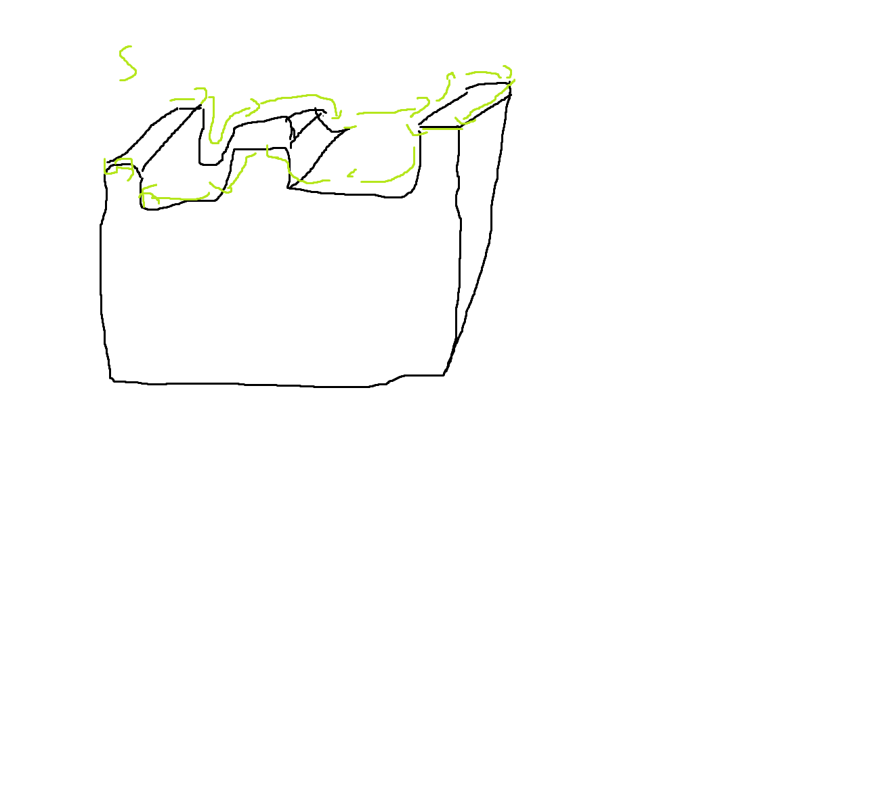
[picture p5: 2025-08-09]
research case 2025-08-03/thinkin palm rest design.png

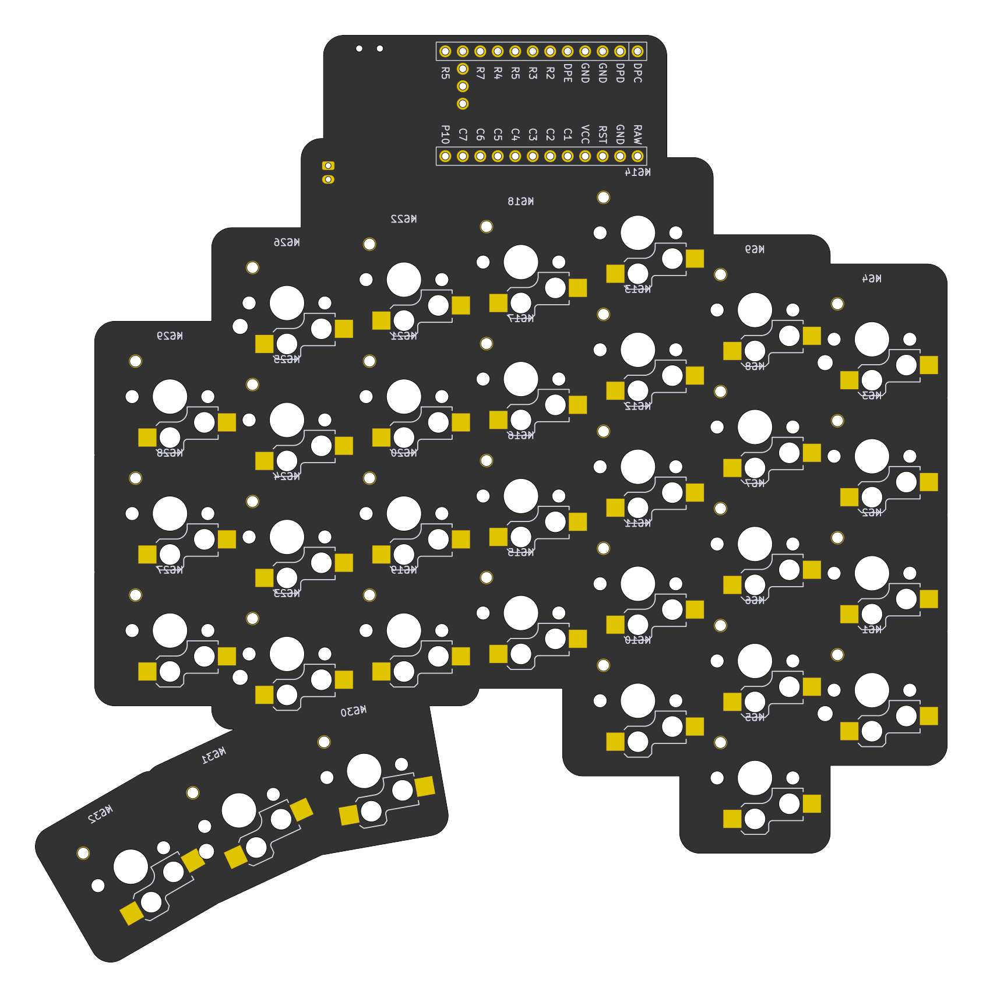
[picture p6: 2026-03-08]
filtered-output/pcbs/images/left_pcb-bottom.png

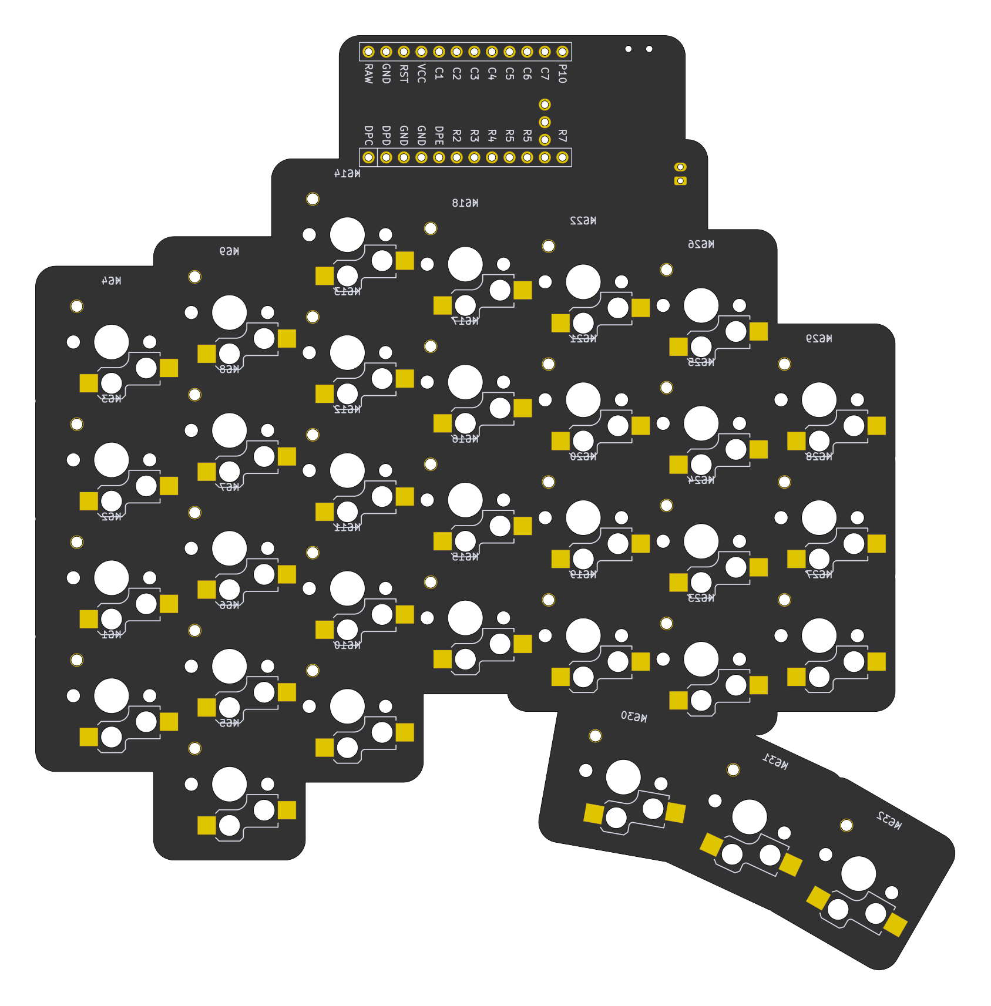
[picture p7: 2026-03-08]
filtered-output/pcbs/images/right_pcb-bottom.png

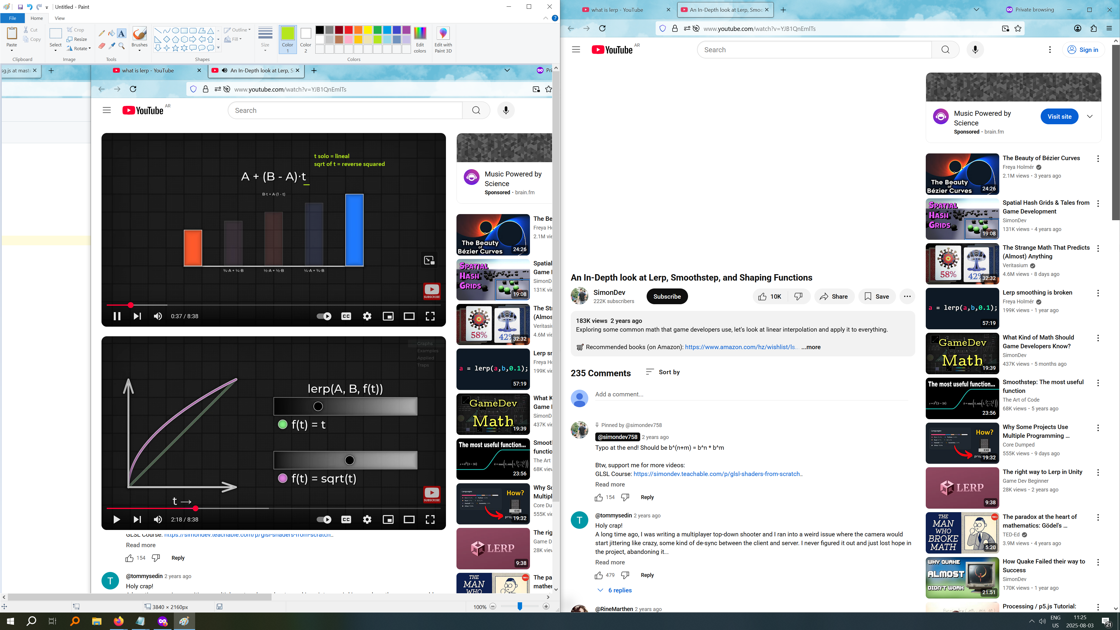
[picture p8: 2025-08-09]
research case 2025-08-03/lerp image.png

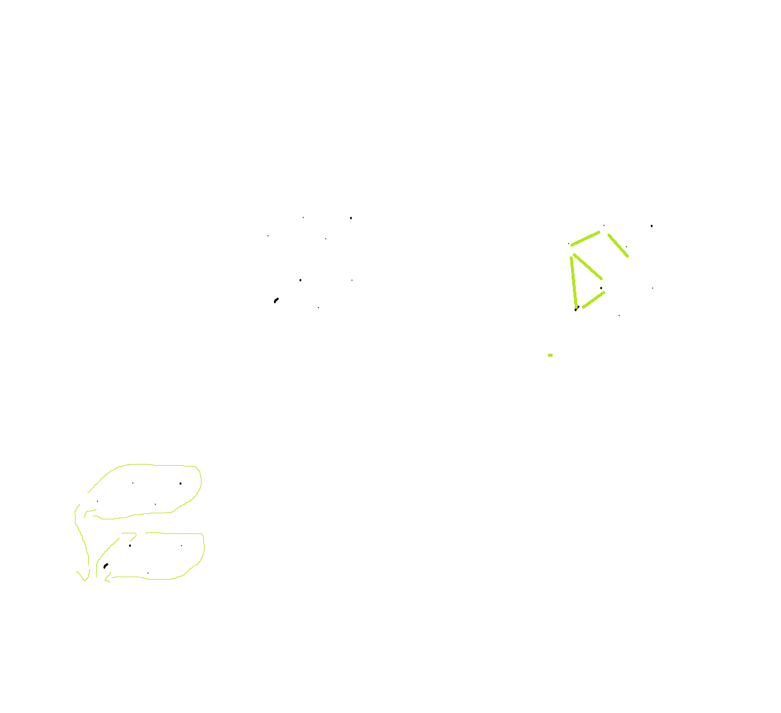
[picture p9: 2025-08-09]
research case 2025-08-03/face drawing.png

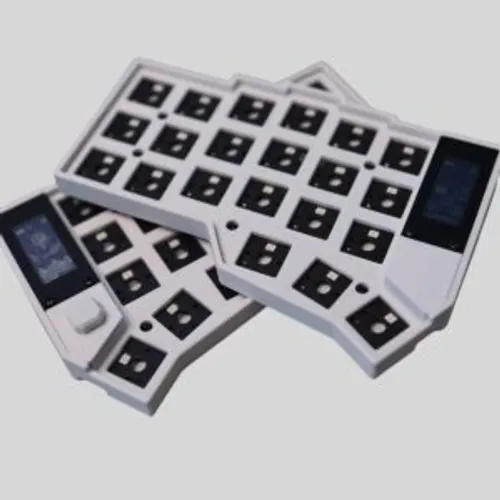
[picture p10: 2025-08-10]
research case 2025-08-03/Plate reference photo pandakb-split-keyboard-Ergonomic-keyboard-zmk-corne-j-choc-nicenano-niceView-wireless-kit-1-300x300.jpg

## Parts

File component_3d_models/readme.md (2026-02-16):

Contains 3d models used to display the 3d file for the keyboard

https://www.printables.com/model/246551-m2-standoff-multiple-sizes is the source for m2 standoffs of size 6 - 10 mm tall, i created the models 1 to 5 mm by scaling the height of the 10mm standoff.

https://github.com/infused-kim/kb_ergogen_fp/tree/main/3d_models is the source for:
Choc_V1_Keycap_MBK_White_1u
Choc_V1_Hotswap
Choc_V1_Switch
Nice_Nano_V2 (wrl created with https://imagetostl.com/convert/file/step/to/wrl#convert)
PinHeader_2.54mm_2x-12 (needed to make the nice nano hotswapable, covers the sides) PinHeader_2.54mm_2x-12 . The 3 pin header used by nice nano is likely [this one](https://www.digikey.hk/en/models/859444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), or [this one](https://www.digikey.com/en/models/298245?tab=snapmagic) but they are generally unnecessary and [for compatibility with promicro or elite-c its generally better to just go with the side pins ](https://github.com/bstiq/nice-nano-kicad) 
And has others that may be useful (power buttons, pin headers, etc). Could not find the 3d model for the spring headers, but they are slightly less tall, and require 0.8-0.9mm holes (which at some point i verified my pcb already uses by default)

The rest of the pin headers were obtained from: https://kicad.github.io/packages3d/Connector_PinHeader_2.54mm
12 are for promicro compatible, 7 are for xiao ble, 4 are exclusively for RP2040Zero (from waveshare), along with the 10s.

For general purposes. Take look at this: https://kicad.github.io/packages3d/

The step file for the rp zero is from here: https://files.waveshare.com/upload/f/f7/RP2040_Zero_stp.zip

Here you can find the files for xiao ble https://wiki.seeedstudio.com/XIAO_BLE/

It also contaisn instructions with how to use them https://github.com/infused-kim/kb_ergogen_fp but i think nowadays its better to use celoides footprint parameters https://github.com/ceoloide/ergogen-footprints/blob/main/switch_choc_v1_v2.js

https://grabcad.com/library/kailh-low-profile-mechanical-keyboard-switch-1
Choc alternative: kailh-low-profile-mechanical-keyboard-switch-1.snapshot.1 

https://grabcad.com/library/kailh-low-profile-mechanical-keyboard-switch-pg1353-1
choc v2: kailh-low-profile-mechanical-keyboard-switch-pg1353-1.snapshot.6

relegendable keycaps
https://grabcad.com/library/mx-cherry-relegendable-keycaps-1
mx-cherry-relegendable-keycaps-1.snapshot.6

More potentially useful switches https://github.com/kiswitch/kiswitch

3d files for printing dummy chocv2 and v1
https://www.printables.com/model/716753-kaliah-choc-v1-v2-dummy/files

lot more models including silents: https://github.com/koktoh/keyswitch_model

From [the builtin diodes library](https://kicad.github.io/packages3d/Diode_SMD)
D_SOD-123.step 

[from snap magic](https://www.snapeda.com/parts/SSSS811101/ALPS/view-part/?company=-&amp;welcome=home) ALPS power switch SSSS811101--3DModel-STEP-269445

from [componentsearchengnine](https://componentsearchengine.com/part-view/EVQ-PUC02K/Panasonic) EVQ-PUC02K, WRL created with [imagetostl](https://imagetostl.com/convert/file/step/to/wrl#convert)

from [snapmagic](https://www.snapeda.com/parts/S2B-PH-K-S(LF)(SN)/JST/view-part/) the JSTPH2 S2B-PH-K-S(LF)(SN) 3d model, and its wrl created with [imagetostl](https://imagetostl.com/convert/file/step/to/wrl#convert)

IMPORTANT, THE NICE NANO + the headers is still less tall than the switches, but not by much
https://typeractive.xyz/pages/build#corne_choc

We need to get new standoff models they are incorrect ( too big)

It seems maybe they were correct ? are standoffs meassured differently from screws? the new 3d model also has much wider side than the m2 scrws

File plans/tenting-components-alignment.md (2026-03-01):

# Tenting Components Alignment Plan

## Problem Statement

The final preview's components (Case, PCB, L_Cover, Palm_Rest) need to be tented at the same angle as the tenting system (6.5 degrees) so they sit on top of it instead of going through it.

## Current State Analysis

### Tenting System Creation
From [`create_tenting_system.py`](../palmrest_and_tenting_creation/create_tenting_system.py):
- **Tenting angle**: 6.5 degrees (`SLOPE_ANGLE_DEG = 6.5`)
- **Slope direction**: Z increases as X increases (line 32: `z = z_min + tan(angle) * (x - x_smallest)`)
- **Minimum height**: `Z_MIN = 3.0` mm
- **Pivot point**: At the smallest X coordinate of the polygon

### Current Transformations in create_full_3d_visual.py
From [`create_full_3d_visual.py`](../create_full_3d_visual.py):
1. **STL rotation**: -90° around X-axis (lines 27-31) to align with PCB orientation
2. **PCB translation**: +7 units along Y-axis (line 248)
3. **L_Cover translation**: -12 units along Y-axis (line 325)

### Coordinate System After -90° X Rotation
When rotating -90° around X-axis:
- Original X → stays as X
- Original Y → becomes Z (upward)
- Original Z → becomes -Y

So the tenting slope (originally Z increasing with X) becomes Y increasing with X after rotation.

## Solution

### Rotation Details
- **Angle**: 6.5 degrees (same as tenting system)
- **Axis**: X-axis (same as tenting system slope direction)
- **Direction**: Positive rotation to tilt the "tall" end up
- **Pivot**: Should be at the smallest X coordinate to match tenting system behavior

### Components to Rotate
All components that sit on top of the tenting system:
1. **Case** - the main keyboard case
2. **PCB** - the printed circuit board with components
3. **L_Cover** - the cover plate
4. **Palm_Rest** - the palm rest area

**Note**: The Tenting_System itself should NOT be rotated - it already has the slope built in.

## Implementation Plan

### Step 1: Add Tenting Angle Constant
Add a constant at the top of the file for the tenting angle:
```python
TENTING_ANGLE_DEG = 6.5  # Must match create_tenting_system.py
```

### Step 2: Modify create_glb_from_stls Function
Apply the tenting rotation to STL meshes (except Tenting_System) in the `create_glb_from_stls` function:

```python
def create_glb_from_stls(stl_files: dict, output_path: str) -> str:
    scene = trimesh.Scene()
    
    # -90° rotation around X-axis (existing)
    rotation_matrix = trimesh.transformations.rotation_matrix(
        angle=-1.5708,
        direction=[1, 0, 0],
        point=[0, 0, 0]
    )
    
    # Tenting rotation: 6.5° around X-axis
    tenting_angle_rad = np.deg2rad(TENTING_ANGLE_DEG)
    tenting_matrix = trimesh.transformations.rotation_matrix(
        angle=tenting_angle_rad,
        direction=[1, 0, 0],
        point=[0, 0, 0]  # Rotate around origin
    )
    
    for node_name, stl_path in stl_files.items():
        if os.path.exists(stl_path):
            mesh = trimesh.load(stl_path, force="mesh")
            mesh.apply_transform(rotation_matrix)  # Existing -90° rotation
            
            # Apply tenting rotation to all EXCEPT Tenting_System
            if node_name != "Tenting_System":
                mesh.apply_transform(tenting_matrix)
            
            scene.add_geometry(mesh, node_name=node_name, geom_name=node_name)
```

### Step 3: Modify merge_glb_files Function
Apply the tenting rotation to the PCB nodes. This requires rotating the root node of the PCB:

```python
# After moving PCB upward, also apply tenting rotation
if hasattr(pcb_gltf, 'scenes') and pcb_gltf.scenes and pcb_gltf.scenes[0].nodes:
    root_node_idx = pcb_gltf.scenes[0].nodes[0]
    root_node = pcb_gltf.nodes[root_node_idx]
    
    # Create rotation quaternion for 6.5° around X-axis
    tenting_angle_rad = np.deg2rad(TENTING_ANGLE_DEG)
    # Quaternion for rotation around X-axis: (cos(θ/2), sin(θ/2), 0, 0)
    half_angle = tenting_angle_rad / 2
    rotation_quaternion = [
        np.cos(half_angle),  # w
        np.sin(half_angle),  # x
        0,                   # y
        0                    # z
    ]
    
    # Combine with existing rotation if any
    if hasattr(root_node, 'rotation') and root_node.rotation:
        # Multiply quaternions (existing * new)
        existing_quat = root_node.rotation
        root_node.rotation = quaternion_multiply(existing_quat, rotation_quaternion)
    else:
        root_node.rotation = rotation_quaternion
```

### Step 4: Adjust Vertical Positioning
The tenting rotation will change the effective height of components. May need to adjust:
- PCB Y translation (currently +7)
- L_Cover Y translation (currently -12)

This may require testing to find optimal values.

## Technical Considerations

### Quaternion Multiplication Helper
Need to add a helper function for quaternion multiplication:
```python
def quaternion_multiply(q1, q2):
    """Multiply two quaternions q1 * q2."""
    w1, x1, y1, z1 = q1
    w2, x2, y2, z2 = q2
    return [
        w1*w2 - x1*x2 - y1*y2 - z1*z2,
        w1*x2 + x1*w2 + y1*z2 - z1*y2,
        w1*y2 - x1*z2 + y1*w2 + z1*x2,
        w1*z2 + x1*y2 - y1*x2 + z1*w2
    ]
```

### glTF Rotation Format
glTF uses quaternions in format `[x, y, z, w]` (not `[w, x, y, z]`), so adjust accordingly:
```python
rotation_quaternion = [
    np.sin(half_angle),  # x
    0,                   # y
    0,                   # z
    np.cos(half_angle)   # w
]
```

## Summary of Changes

| File Section | Change |
|---|---|
| Constants | Add `TENTING_ANGLE_DEG = 6.5` |
| `create_glb_from_stls()` | Apply tenting rotation to all STL meshes except Tenting_System |
| `merge_glb_files()` | Apply tenting rotation to PCB root node via quaternion |
| Helper functions | Add `quaternion_multiply()` function |

## Testing

After implementation:
1. Run `python create_full_3d_visual.py`
2. Open `./filtered-output/combined_scene.glb` in a 3D viewer
3. Verify all components sit on top of the tenting system
4. Check that there's no intersection between components and tenting system

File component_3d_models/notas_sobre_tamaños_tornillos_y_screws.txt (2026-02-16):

alto spacers tiene que ser la cantidad que quiero que entre del screw de cada lado * 2 + un cierto minimo para evitar issues. la cantidad que quiero que entre seguramente 1mm este bien:?
5mm thread tornillo parce estar bien, para que 4mm entre appox  menos que 3mm adentro de tandoff parece demasiado poco.

m1.7 o 1.6 tal vez se pueden usar tambien y parecen venir mas chicos.

Lo mejor parecen ser pancake screws o ultra-low-profile
https://grabcad.com/library/pancake-screws-1 https://mx.misumi-ec.com/en/vona2/detail/221000546066/
parece que se puede bajar el cad en la segunda página que vede screws reales!

pan head parece ser el redondeado hacia afuera, que tampoco sería algo muy grave

ACA HAY MAS MODELOS DISPONIBLES BIEN PLANOS MULTIPLE LENGTH Y INCLUSO SE PUEDE COMPRAR
https://mx.misumi-ec.com/en/vona2/detail/221000546066/

3mf flat head screws https://www.printables.com/model/1279599-m2-m10-phillips-screws-in-all-sorts-of-lengths-inc/files

ACA HAY TUERCAS IMPRIMIBLES https://www.printables.com/model/1279649-m2-m22-hex-shaped-nuts-incl-step/files

m3 screws https://grabcad.com/library/cross-recessed-phillips-countersunk-flat-head-screws-m3-1
m2.5 https://grabcad.com/library/cross-recessed-phillips-countersunk-flat-head-screws-m2-5-1

https://www.mcmaster.com/products/pan-head-machine-screws/length~2-mm/?s=m2+pan+head+machine+screws https://www.mcmaster.com/92005A010/
https://www.mcmaster.com/products/pan-head-machine-screws/length~3-mm/stainless-steel-pan-head-phillips-screws~~/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 black oxide https://www.mcmaster.com/95836A103/
https://www.mcmaster.com/products/pan-head-machine-screws/stainless-steel-pan-head-phillips-screws~~/length~4-mm/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 https://www.mcmaster.com/92000A011/
https://www.mcmaster.com/products/pan-head-machine-screws/stainless-steel-pan-head-phillips-screws~~/length~5-mm/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  https://www.mcmaster.com/92000A012/

https://www.mcmaster.com/products/pan-head-machine-screws/stainless-steel-pan-head-phillips-screws~~/length~6-mm/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  https://www.mcmaster.com/92000A013/

https://www.mcmaster.com/products/pan-head-machine-screws/stainless-steel-pan-head-phillips-screws~~/length~8-mm/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 https://www.mcmaster.com/92000A015/

https://www.mcmaster.com/products/pan-head-machine-screws/stainless-steel-pan-head-phillips-screws~~/length~10-mm/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 https://www.mcmaster.com/92000A017/

https://www.mcmaster.com/products/pan-head-machine-screws/stainless-steel-pan-head-phillips-screws~~/length~12-mm/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 https://www.mcmaster.com/92000A019/

https://www.traceparts.com/en/product/din-cross-recessed-countersunk-flat-head-screws-common-head-style-type-h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

https://www.mcmaster.com/products/screws/system-of-measurement~metric/socket-head-profile~ultra-low/socket-head-screws-2~/socket-head-profile~low/thread-size~m2/leng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 https://www.mcmaster.com/mvD/Library/CAD2/20260108/53AE5A4D/93070A274_Alloy%20Steel%20Low-Profile%20Socket%20Head%20Screw.STEP

https://www.mcmaster.com/products/screws/system-of-measurement~metric/socket-head-profile~ultra-low/socket-head-screws-2~/socket-head-profile~low/thread-size~m2/leng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

https://www.mcmaster.com/products/screws/system-of-measurement~metric/socket-head-profile~ultra-low/socket-head-screws-2~/socket-head-profile~low/thread-size~m2/leng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  https://www.mcmaster.com/93070A276

https://www.mcmaster.com/products/screws/system-of-measurement~metric/socket-head-profile~ultra-low/socket-head-screws-2~/socket-head-profile~low/thread-size~m2/leng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 https://www.mcmaster.com/93070A277

https://www.mcmaster.com/products/screws/system-of-measurement~metric/socket-head-profile~ultra-low/socket-head-screws-2~/socket-head-profile~low/thread-size~m2/leng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 https://www.mcmaster.com/93070A278

https://www.mcmaster.com/products/screws/system-of-measurement~metric/socket-head-profile~ultra-low/socket-head-screws-2~/socket-head-profile~low/thread-size~m2/leng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 https://www.mcmaster.com/92855A841

comprar m2 screws
barato pero incierto
https://articulo.mercadolibre.com.ar/MLA-1532424915-m2-14-40-tornillos-de-cabeza-plana-de-acero-inoxidable-_JM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 

Inmediato y adecuado no tan caro (pero solo 4 6 8 10 12 tamaños (no 5)
https://www.mercadolibre.com.ar/kit-470-tornillos-allen-plano-m2-m3-m4-acero-inoxidable/up/MLAU3666254373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

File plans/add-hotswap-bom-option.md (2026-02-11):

# Plan: Enhanced BOM Control for Switch Footprint

## Problem Statement

The hotswap sockets in the Choc v1/v2 switch footprint are currently hardcoded to be excluded from the Bill of Materials (BOM). This prevents users from including hotswap sockets in their BOM when ordering components.

## Solution Overview

The implementation has evolved through multiple approaches:

1. **Initial approach (deprecated):** Modified the switch footprint to include BOM control parameters
2. **Current approach (recommended):** Separate virtual footprints for hotswap sockets and keycaps

Since KiCad only allows one `attr` line per footprint, it's impossible to have a single footprint generate multiple separate BOM entries for its internal components (hotswap socket, switch, keycap). To work around this limitation, separate virtual footprints have been created.

## Current Implementation

### Main Switch Footprint: switch_choc_v1_v2.js

The main switch footprint ([`ergogen/footprints/ceoloide/switch_choc_v1_v2.js`](ergogen/footprints/ceoloide/switch_choc_v1_v2.js)) now includes:

**Parameters:**
- `switch_supplier_link` - Supplier link for switches
- `switch_mpn` - Manufacturer part number for switches
- `switch_do_not_populate` - DNP flag for switches (default: 'DNP')
- `switch_3dmodel_filename`, `switch_3dmodel_xyz_offset`, `switch_3dmodel_xyz_rotation`, `switch_3dmodel_xyz_scale` - 3D model configuration

**Note:** The main switch footprint does NOT include hotswap socket or keycap parameters. Those are handled by separate virtual footprints.

### Virtual Hotswap Socket Footprint: hs-socket-fab-preview_choc_v1_v2.js

Created a minimal virtual footprint at [`ergogen/footprints/ceoloide/hs-socket-fab-preview_choc_v1_v2.js`](ergogen/footprints/ceoloide/hs-socket-fab-preview_choc_v1_v2.js) that:

- **Designator:** 'HS' (Hotswap Socket)
- **Adds NOTHING to the PCB:** No pads, holes, or silkscreen
- **Only provides:**
  - 3D model for the hotswap socket
  - BOM entry for hotswap sockets
  - POS file entry for hotswap sockets
  - KiCad properties for supplier link, MPN, and DNP flag

**Parameters:**
```javascript
side: 'B'                              // Board side for reference
hotswap_3dmodel_filename: ''           // Path to 3D model file
hotswap_3dmodel_xyz_offset: [0, 0, 0]  // 3D model offset
hotswap_3dmodel_xyz_rotation: [0, 0, 0] // 3D model rotation
hotswap_3dmodel_xyz_scale: [1, 1, 1]   // 3D model scale
hotswap_supplier_link: ''              // Supplier URL
hotswap_mpn: ''                        // Manufacturer part number
hotswap_do_not_populate: ''            // DNP flag (default: '')
```

### Virtual Keycap Footprint: keycap-fab-preview_choc_v1_v2.js

Created a minimal virtual footprint at [`ergogen/footprints/ceoloide/keycap-fab-preview_choc_v1_v2.js`](ergogen/footprints/ceoloide/keycap-fab-preview_choc_v1_v2.js) that:

- **Designator:** 'KC' (Keycap)
- **Adds NOTHING to the PCB:** No pads, holes, or silkscreen
- **Only provides:**
  - 3D model for the keycap
  - BOM entry for keycaps
  - POS file entry for keycaps
  - KiCad properties for supplier link, MPN, and DNP flag

**Parameters:**
```javascript
side: 'B'                              // Board side for reference
keycap_3dmodel_filename: ''            // Path to 3D model file
keycap_3dmodel_xyz_offset: [0, 0, 0]   // 3D model offset
keycap_3dmodel_xyz_rotation: [0, 0, 0] // 3D model rotation
keycap_3dmodel_xyz_scale: [1, 1, 1]    // 3D model scale
keycap_supplier_link: ''               // Supplier URL
keycap_mpn: ''                         // Manufacturer part number
keycap_do_not_populate: 'DNP'          // DNP flag (default: 'DNP')
```

**Note:** The `do_not_populate` flag defaults to 'DNP' for keycaps since manufacturers typically don't populate keycaps during assembly.

### Usage in config.yaml

The current implementation uses separate virtual footprints for hotswap sockets and keycaps. Here's how to configure them:

**Main Switch Footprint (choc):**
```yaml
choc:
  what: ceoloide/switch_choc_v1_v2
  where:
    - [ leftkey]
  adjust:
    rotate: 180
  params:
    include_keycap: true
    choc_v2_support: false
    reversible: false
    hotswap: true
    side: 'B'
    keycap_width: 16.5
    keycap_height: 16.5
    include_in_pos_files: true
    # Supplier Link (optional)
    switch_supplier_link: 'https://kailhswitch.com/products/choc-v1'
    # Manufacturer Part Number (optional)
    switch_mpn: 'Kailh-Choc-PG1350'
    # DNP Flag (optional - set to 'DNP' to indicate the manufacturer should not try to place the part automatically)
    switch_do_not_populate: 'DNP'
    # 3D Model
    switch_3dmodel_filename: "${PATH_TO_SWEEPYWAY_COMPONENT_MODELS}/Choc_V1_Switch.step"
    switch_3dmodel_xyz_rotation: [180, 0, 0]
```

**Hotswap Socket Virtual Footprint (choc_hotswap):**
```yaml
choc_hotswap:
  what: ceoloide/hs-socket-fab-preview_choc_v1_v2
  where:
    - [ leftkey]
  adjust:
    rotate: 180
  params:
    side: 'B'
    # 3D Model
    hotswap_3dmodel_filename: "${PATH_TO_SWEEPYWAY_COMPONENT_MODELS}/Choc_V1_Hotswap.step"
    hotswap_3dmodel_xyz_rotation: [180, 0, 0]
    # Supplier Link (optional)
    hotswap_supplier_link: 'https://kailhswitch.com/products/hotswap-socket'
    # Manufacturer Part Number (optional)
    hotswap_mpn: 'Kailh-Hotswap-PG1350'
    # DNP Flag (optional - set to 'DNP' to indicate the manufacturer should not try to place the part automatically)
    hotswap_do_not_populate: ''
```

**Keycap Virtual Footprint (choc_keycap):**
```yaml
choc_keycap:
  what: ceoloide/keycap-fab-preview_choc_v1_v2
  where:
    - [ leftkey]
  adjust:
    rotate: 180
  params:
    side: 'B'
    # 3D Model
    keycap_3dmodel_filename: "${PATH_TO_SWEEPYWAY_COMPONENT_MODELS}/Choc_V1_Keycap_MBK_White_1u.step"
    keycap_3dmodel_xyz_rotation: [180, 0, 0]
    # Supplier Link (optional)
    keycap_supplier_link: 'https://mechanicalkeyboards.com/product/mbk-choc'
    # Manufacturer Part Number (optional)
    keycap_mpn: 'MBK-Choc-1u-White'
    # DNP Flag (optional - set to 'DNP' to indicate the manufacturer should not try to place the part automatically)
    keycap_do_not_populate: 'DNP'
```

## Usage

### Supplier Links

Add supplier links for easy ordering:

```yaml
params:
  # For switch footprint
  switch_supplier_link: 'https://kailhswitch.com/products/choc-v1'
  
  # For hotswap socket virtual footprint
  hotswap_supplier_link: 'https://kailhswitch.com/products/hotswap-socket'
  
  # For keycap virtual footprint
  keycap_supplier_link: 'https://mechanicalkeyboards.com/product/mbk-choc'
```

### Manufacturer Part Numbers

Add manufacturer part numbers for BOM tracking:

```yaml
params:
  # For switch footprint
  switch_mpn: 'Kailh-Choc-PG1350'
  
  # For hotswap socket virtual footprint
  hotswap_mpn: 'Kailh-Hotswap-PG1350'
  
  # For keycap virtual footprint
  keycap_mpn: 'MBK-Choc-1u-White'
```

### Do Not Populate (DNP) Flags

The `do_not_populate` flag indicates to the manufacturer that they should not try to automatically place the part during assembly.

```yaml
params:
  # For switch footprint (default: 'DNP')
  switch_do_not_populate: 'DNP'    # Don't auto-populate switches
  
  # For hotswap socket virtual footprint (default: '')
  hotswap_do_not_populate: ''      # Auto-populate hotswap sockets
  
  # For keycap virtual footprint (default: 'DNP')
  keycap_do_not_populate: 'DNP'    # Don't auto-populate keycaps
```

**Note:** Set `do_not_populate` to an empty string `''` to allow the manufacturer to auto-populate the part. Set it to `'DNP'` to mark it as do not populate.

## BOM Output Columns

When using KiCad or KiBot to generate BOMs with the virtual footprint approach, you'll get separate entries for each component type:

| Column Name | Description | Example (Switch) | Example (Hotswap) | Example (Keycap) |
|---|---|---|---|---|
| Designator | Footprint designator | S1-S32 | HS1-HS32 | KC1-KC32 |
| Footprint | Footprint name | switch_choc_v1_v2 | hs-socket-fab-preview_choc_v1_v2 | keycap-fab-preview_choc_v1_v2 |
| Supplier Link | URL to supplier | https://kailhswitch.com/products/choc-v1 | https://kailhswitch.com/products/hotswap-socket | https://mechanicalkeyboards.com/product/mbk-choc |
| MPN | Manufacturer part number | Kailh-Choc-PG1350 | Kailh-Hotswap-PG1350 | MBK-Choc-1u-White |
| Do Not Populate | DNP flag | DNP | (empty) | DNP |

## Testing

After implementing the changes:

1. **Regenerate the PCB files using ergogen:**
    ```bash
    ergogen ergogen/config.yaml
    ```

2. **Check the generated KiCad files to verify:**
    - Open the generated `.kicad_pcb` file
    - Search for switch footprints (designators S1, S2, etc.)
    - Search for hotswap socket virtual footprints (designators HS1, HS2, etc.)
    - Search for keycap virtual footprints (designators KC1, KC2, etc.)
    - Verify KiCad properties are present when supplier links/MPNs are provided

3. **Generate a BOM using KiBot:**
    ```bash
    kibot -c kibot/jlpcb_bom.kibot.yaml
    ```

4. **Verify the BOM output:**
    - You should see three separate entries for each key position
    - Switch footprints (S1-S32) with switch properties
    - Hotswap socket footprints (HS1-HS32) with hotswap properties
    - Keycap footprints (KC1-KC32) with keycap properties
    - Each should have its own supplier link, MPN, and DNP flag

5. **Test DNP functionality:**
    - Set `switch_do_not_populate: 'DNP'` for some keys
    - Verify those components are marked as DNP in the BOM
    - Set `hotswap_do_not_populate: ''` to allow auto-population
    - Set `keycap_do_not_populate: 'DNP'` to mark keycaps as DNP

6. **Verify 3D preview:**
    - All three 3D models (switch, hotswap socket, keycap) should appear at each key position
    - The virtual footprints should not interfere with the actual switch footprint

## Summary of Changes

### Cleanup Changes (2026-02-11)

The following cleanup changes were made to simplify the implementation:

1. **Removed unused parameters from switch_choc_v1_v2.js:**
   - Removed: `hotswap_mpn`, `keycap_mpn`
   - Removed: `include_hotswap_in_bom`, `include_switch_in_bom`, `include_keycap_in_bom`
   - Removed: `hotswap_3dmodel_filename`, `hotswap_3dmodel_xyz_offset`, `hotswap_3dmodel_xyz_rotation`, `hotswap_3dmodel_xyz_scale`
   - Removed: `keycap_3dmodel_filename`, `keycap_3dmodel_xyz_offset`, `keycap_3dmodel_xyz_rotation`, `keycap_3dmodel_xyz_scale`
   - Removed: `hotswap_supplier_link`, `keycap_supplier_link`
   - Removed: `from` parameter (not needed for switch footprint)

2. **Renamed `dnp` to `do_not_populate` in all footprints:**
   - `switch_dnp` → `switch_do_not_populate`
   - `hotswap_dnp` → `hotswap_do_not_populate`
   - `keycap_dnp` → `keycap_do_not_populate`

3. **Set default values for `do_not_populate`:**
   - `switch_do_not_populate: 'DNP'` (default)
   - `hotswap_do_not_populate: ''` (default)
   - `keycap_do_not_populate: 'DNP'` (default)

4. **Updated config.yaml to remove unused parameters:**
   - Removed all unused parameters from switch footprint calls in `left_pcb` and `right_pcb` sections
   - Kept only relevant parameters for each footprint type

5. **Clarified documentation:**
   - Updated documentation to reflect the virtual footprint approach as the recommended solution
   - Clarified that `do_not_populate` indicates the manufacturer should not try to place the part automatically

### Files Modified

- [`ergogen/footprints/ceoloide/switch_choc_v1_v2.js`](ergogen/footprints/ceoloide/switch_choc_v1_v2.js) - Main switch footprint
- [`ergogen/footprints/ceoloide/hs-socket-fab-preview_choc_v1_v2.js`](ergogen/footprints/ceoloide/hs-socket-fab-preview_choc_v1_v2.js) - Hotswap socket virtual footprint
- [`ergogen/footprints/ceoloide/keycap-fab-preview_choc_v1_v2.js`](ergogen/footprints/ceoloide/keycap-fab-preview_choc_v1_v2.js) - Keycap virtual footprint
- [`ergogen/config.yaml`](ergogen/config.yaml) - Configuration file
- [`plans/add-hotswap-bom-option.md`](plans/add-hotswap-bom-option.md) - Documentation

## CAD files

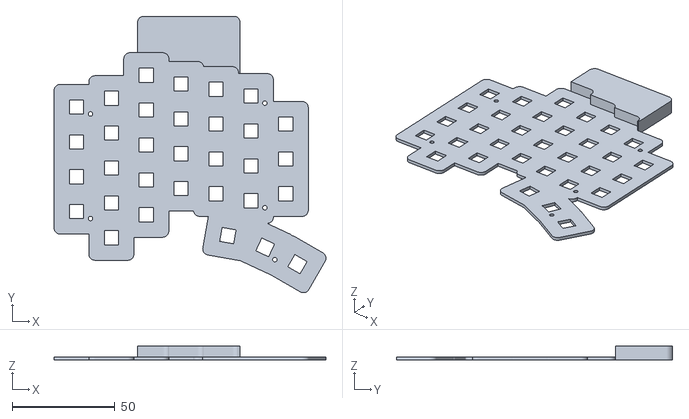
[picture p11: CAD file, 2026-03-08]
filtered-output/cases/l_cover.stl
132.6 x 134.8 x 7.00

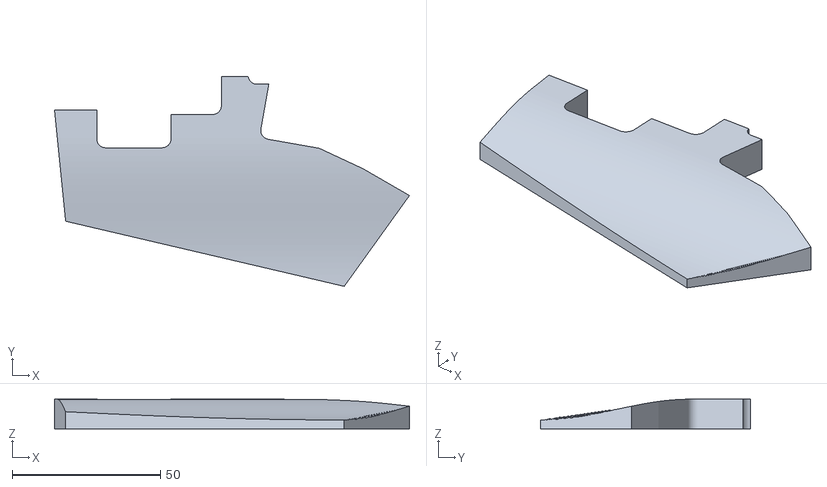
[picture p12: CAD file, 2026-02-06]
filtered-output/palmrest/palm_rest.stl
119.6 x 70.7 x 10.0

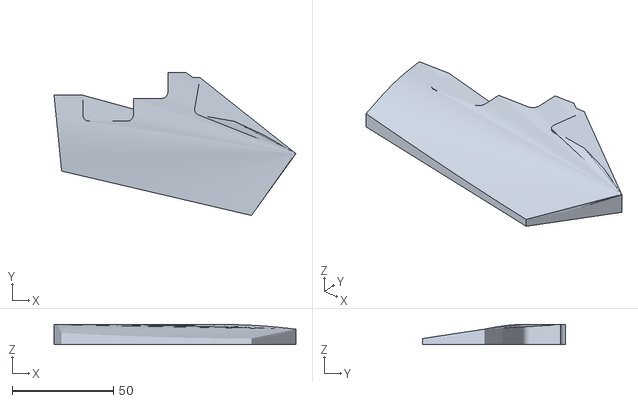
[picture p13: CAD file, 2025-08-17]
research case 2025-08-03/pymodeling_tests/lofted_polyhedron_refactored_s.stl
119.6 x 70.7 x 10.0

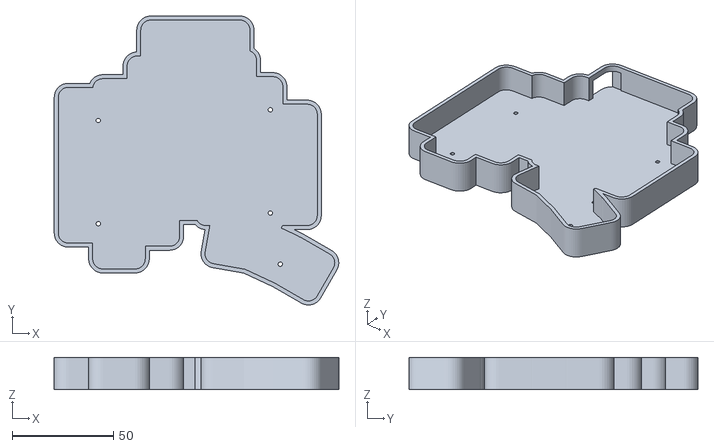
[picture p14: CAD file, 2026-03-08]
filtered-output/cases/l_case_3d.stl
140.6 x 142.8 x 16.0

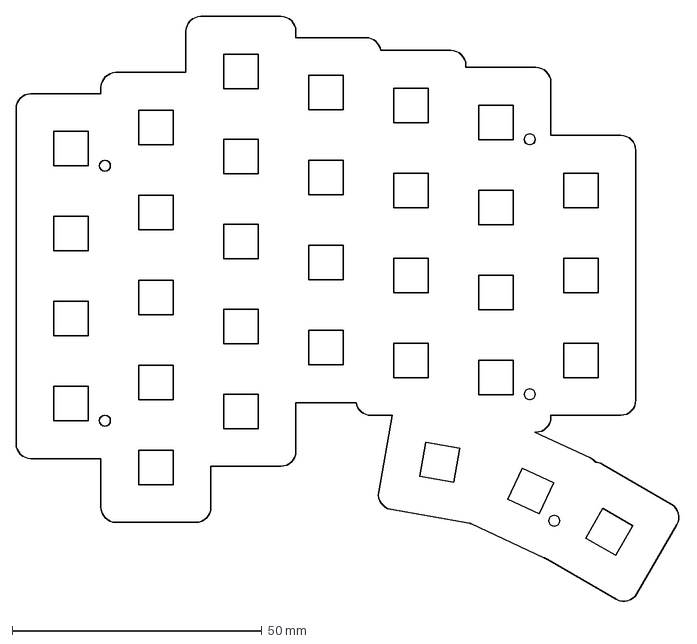
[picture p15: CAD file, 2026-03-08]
filtered-output/pcbs/outlines/l_coverpart_switch_plate_outline.dxf
133.0 x 117.5 mm

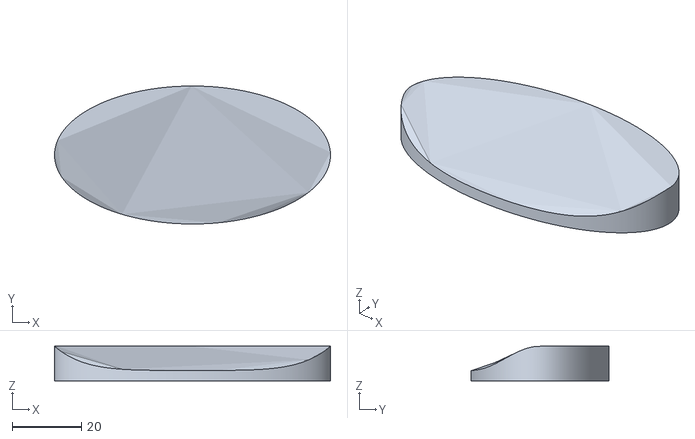
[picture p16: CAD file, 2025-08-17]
research case 2025-08-03/pymodeling_tests/lofted_polyhedron_final.stl
80.0 x 40.0 x 10.0

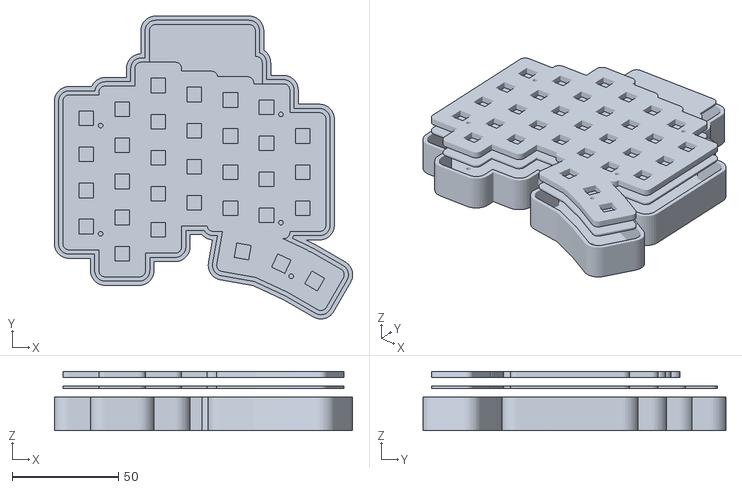
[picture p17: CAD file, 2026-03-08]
filtered-output/cases/l_3d_preview.stl
140.6 x 142.8 x 28.0

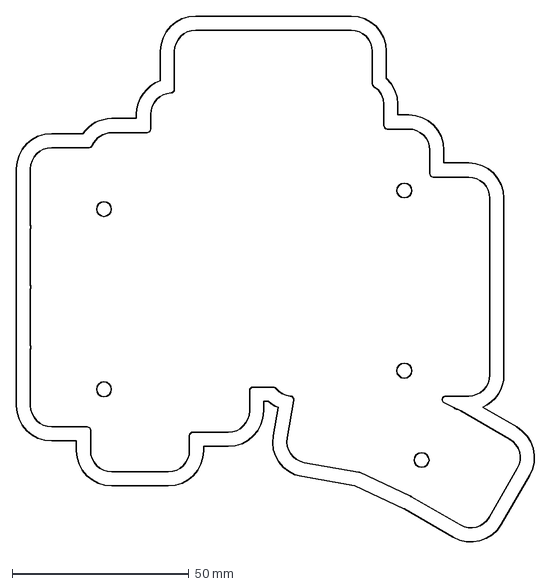
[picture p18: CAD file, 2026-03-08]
filtered-output/pcbs/outlines/l_tenting_base_border_outline.dxf
147.0 x 150.2 mm

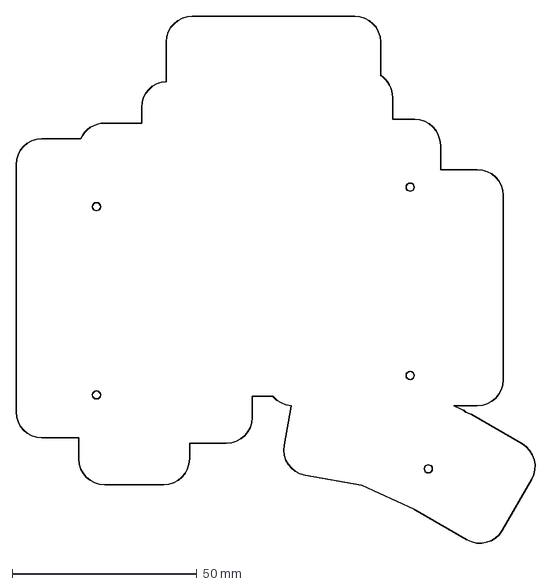
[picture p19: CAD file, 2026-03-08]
filtered-output/pcbs/outlines/l_case_bottom.dxf
140.9 x 143.8 mm

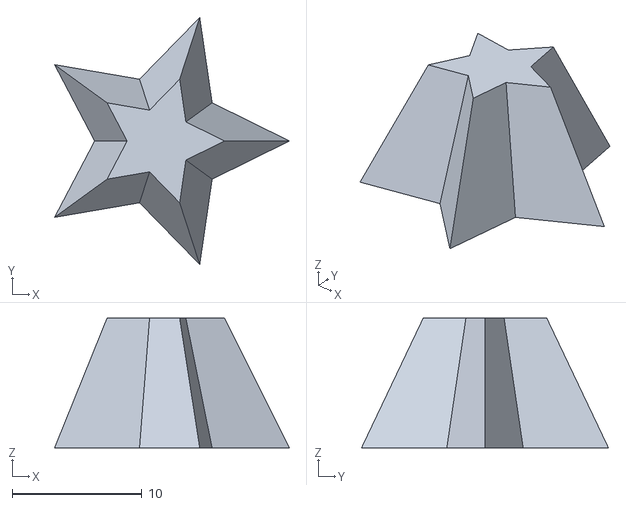
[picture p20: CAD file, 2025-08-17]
research case 2025-08-03/pymodeling_tests/star_loft_cadquery.stl
18.1 x 19.0 x 10.0

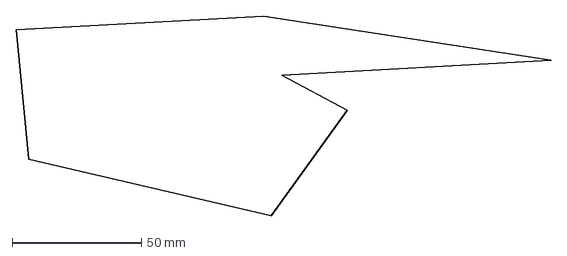
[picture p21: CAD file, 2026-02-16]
filtered-output/pcbs/outlines/l_hand_rest_overlapping_polygon.dxf
207.2 x 77.2 mm

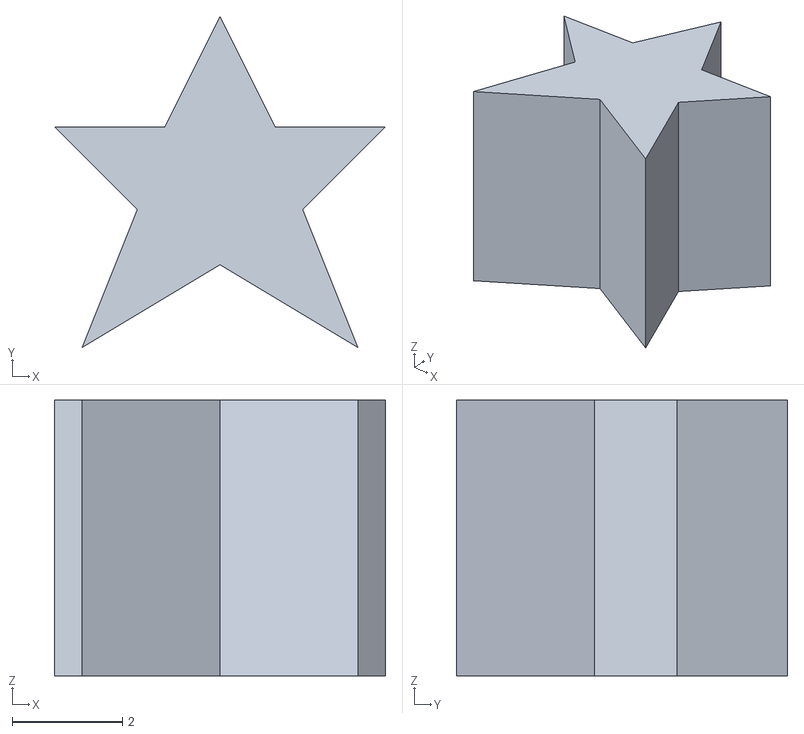
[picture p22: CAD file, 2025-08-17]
research case 2025-08-03/pymodeling_tests/star_lofted.stl
6.00 x 6.00 x 5.00

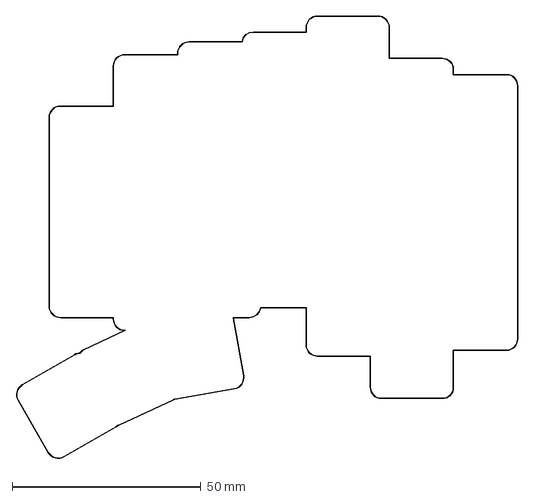
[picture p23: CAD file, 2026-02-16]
filtered-output/pcbs/outlines/r_all_key_clusters_outline.dxf
132.7 x 117.5 mm

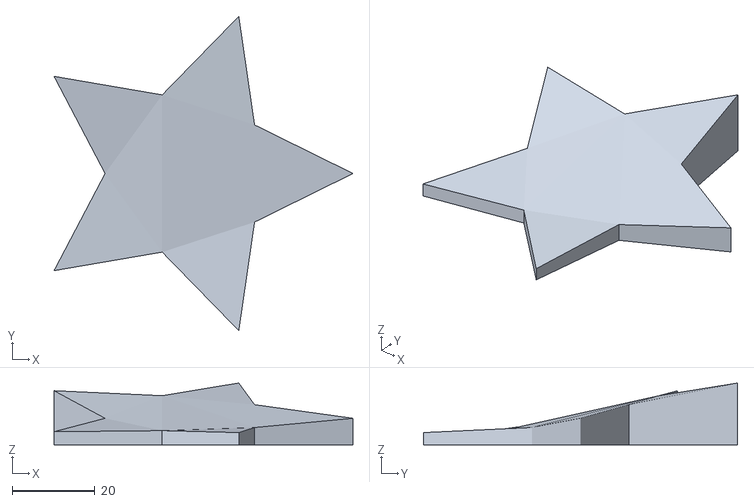
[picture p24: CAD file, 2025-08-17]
research case 2025-08-03/pymodeling_tests/star_lofted_slope.stl
72.4 x 76.1 x 15.0

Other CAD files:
research case 2025-08-03/pymodeling_tests/lofted_polyhedron_opta2.stl
filtered-output/pcbs/outlines/l_hand_rest_polygon.dxf
research case 2025-08-03/pymodeling_tests/lofted_polyhedron_clean.stl
filtered-output/pcbs/outlines/r_controller_area_border.dxf
component_3d_models/92000A011_Passivated_18-8_Stainless_Steel_Pan_Head_Phillips_Screw_m2_4mm.STEP
component_3d_models/92000A012_Passivated_18-8_Stainless_Steel_Pan_Head_Phillips_Screw_m2_5mm.STEP
component_3d_models/92000A013_Passivated_18-8_Stainless_Steel_Pan_Head_Phillips_Screw_m2_6mm.STEP
component_3d_models/92000A015_Passivated_18-8_Stainless_Steel_Pan_Head_Phillips_Screw_m2_8mm.STEP
component_3d_models/92000A017_Passivated_18-8_Stainless_Steel_Pan_Head_Phillips_Screw_m2_10mm.STEP
component_3d_models/92000A019_Passivated_18-8_Stainless_Steel_Pan_Head_Phillips_Screw_m2_12mm.STEP
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

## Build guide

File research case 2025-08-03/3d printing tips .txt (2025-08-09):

todo 1 mm width o mas (menos dificil bien con width filamento estandard)
arms requieren overhang, overhang triangles dont
circulos son mas faciles que corners

no trates de ahuecar,, se puede llenar con honicomb structure

puttexture on your part to hide layer lines

if things need to go together make small preassure relieaving lines or smething

try to minimize first layer contact (and support)

https://www.youtube.com/watch?v=Bd7Yyn61XWQ&pp=0gcJCccJAYcqIYzv

https://www.youtube.com/watch?v=Bd7Yyn61XWQ&pp=0gcJCccJAYcqIYzv

https://www.youtube.com/watch?v=CxbidoZCw1A

https://www.freecad.org/
https://openscad.org/

meshmixter: fix 

https://www.youtube.com/watch?v=CfyvdsrkPCM

https://www.youtube.com/watch?v=1Ff_NcZhBSo

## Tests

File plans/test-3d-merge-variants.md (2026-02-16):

# Plan: Test Multiple 3D Merge Variants Simultaneously

## Problem Summary

The unified 3D scene (`combined_scene.glb`) has two issues:
1. **All switches are stacked at a single location** - transforms are lost
2. **PCB orientation is wrong** - rotation transform is lost

## Root Cause Analysis

In [`create_full_3d_visual.py`](../create_full_3d_visual.py:44-59), the current code:

```python
for node_name, geometry in left_pcb_scene.geometry.items():
    scene.add_geometry(
        geometry,
        node_name=f"Left_PCB_{node_name}",
        geom_name=f"Left_PCB_{node_name}"
    )
```

**Problem**: `scene.geometry.items()` returns raw geometries **without their transforms**. In trimesh, transforms are stored in the scene graph (`scene.graph`), not in the geometry objects.

## Testing Strategy: Create Multiple Variants

To minimize GitHub Actions pushes, we'll create **5 test variants** that will all be generated in a single run:

### Variant 1: Current Implementation (Baseline)
**File**: `create_full_3d_visual_v1_baseline.py`

Keep the current implementation as-is to have a baseline for comparison.

**Expected**: Switches stacked at origin, wrong PCB orientation.

---

### Variant 2: Use Scene Graph Transforms
**File**: `create_full_3d_visual_v2_graph_transforms.py`

Apply transforms from the scene graph before adding geometries:

```python
for node_name, geometry in left_pcb_scene.geometry.items():
    # Get the transform for this node from the scene graph
    transform = left_pcb_scene.graph.get(node_name)[0]  # Returns (transform, geometry_name)
    if transform is not None:
        # Apply the transform to a copy of the geometry
        transformed_geom = geometry.copy()
        transformed_geom.apply_transform(transform)
        scene.add_geometry(transformed_geom, ...)
    else:
        scene.add_geometry(geometry, ...)
```

**Expected**: Switches at correct positions, but PCB orientation may still be wrong.

---

### Variant 3: Merge Scenes Directly
**File**: `create_full_3d_visual_v3_scene_merge.py`

Use trimesh's scene merging capability:

```python
# Convert the loaded scene to a single scene with all transforms applied
# Then merge into the main scene
scene.add_geometry(left_pcb_scene.to_mesh(), ...)
```

Or use:
```python
# Add the entire scene at once
for name, geom in left_pcb_scene.geometry.items():
    # Get the world transform for this geometry
    world_transform = left_pcb_scene.graph.get(name)[0]
    scene.add_geometry(geom, transform=world_transform, ...)
```

**Expected**: All transforms preserved, but may have double-transform issues.

---

### Variant 4: Iterate Over Scene Graph Edges
**File**: `create_full_3d_visual_v4_graph_edges.py`

Traverse the scene graph properly using edges:

```python
# The scene.graph contains the actual transforms
# Each edge in the graph represents a parent->child relationship with a transform
for edge in left_pcb_scene.graph.edges:
    transform, geometry_name = left_pcb_scene.graph.get(edge[1])
    if geometry_name in left_pcb_scene.geometry:
        geom = left_pcb_scene.geometry[geometry_name]
        transformed = geom.copy()
        transformed.apply_transform(transform)
        scene.add_geometry(transformed, ...)
```

**Expected**: Correct transforms for all components.

---

### Variant 5: Export and Re-import
**File**: `create_full_3d_visual_v5_reexport.py`

Export the PCB scene to a temporary file and re-import:

```python
# Export the PCB scene to bytes
pcb_bytes = left_pcb_scene.export(file_type='glb')
# Re-import as a single mesh with transforms baked in
pcb_mesh = trimesh.load(trimesh.util.BytesIO(pcb_bytes), file_type='glb', force='mesh')
scene.add_geometry(pcb_mesh, ...)
```

**Expected**: All transforms baked into geometry, correct positions.

---

### Variant 6: Apply Transform to Scene Before Adding
**File**: `create_full_3d_visual_v6_scene_transform.py`

Apply transform to the entire scene before extracting geometries:

```python
# Apply a rotation to the entire PCB scene
rotation = trimesh.transformations.rotation_matrix(np.pi/2, [1, 0, 0])
left_pcb_scene.apply_transform(rotation)

# Now extract geometries - they should have the transform applied
for node_name, geometry in left_pcb_scene.geometry.items():
    scene.add_geometry(geometry, ...)
```

**Expected**: PCB orientation corrected, but switches may still be stacked.

---

## Implementation Plan

### Step 1: Create Test Scripts

Create 6 Python scripts, each implementing one variant:

1. `create_full_3d_visual_v1_baseline.py` - Current implementation
2. `create_full_3d_visual_v2_graph_transforms.py` - Use scene graph transforms
3. `create_full_3d_visual_v3_scene_merge.py` - Merge scenes directly
4. `create_full_3d_visual_v4_graph_edges.py` - Iterate over graph edges
5. `create_full_3d_visual_v5_reexport.py` - Export and re-import
6. `create_full_3d_visual_v6_scene_transform.py` - Apply transform to scene

### Step 2: Modify GitHub Workflow

Update `.github/workflows/build.yaml` to run all variants:

```yaml
- name: Run all 3D merge variants
  run: |
    for variant in v1_baseline v2_graph_transforms v3_scene_merge v4_graph_edges v5_reexport v6_scene_transform; do
      echo "Running variant: $variant"
      uv run python3 "create_full_3d_visual_${variant}.py" || echo "Variant $variant failed"
    done
```

### Step 3: Analyze Results

After the workflow runs, download the artifacts and check:
1. `combined_scene_v1.glb` - Baseline
2. `combined_scene_v2.glb` - Graph transforms
3. `combined_scene_v3.glb` - Scene merge
4. `combined_scene_v4.glb` - Graph edges
5. `combined_scene_v5.glb` - Re-export
6. `combined_scene_v6.glb` - Scene transform

Compare each variant to identify which approach:
- Correctly positions switches
- Correctly orients the PCB
- Preserves materials and colors

---

## Expected Outcomes Matrix

| Variant | Switch Positions | PCB Orientation | Materials Preserved |
|---|---|---|---|
| v1_baseline | ❌ Stacked | ❌ Wrong | ✅ Yes |
| v2_graph_transforms | ✅ Correct | ⚠️ May need rotation | ✅ Yes |
| v3_scene_merge | ⚠️ Unknown | ⚠️ Unknown | ⚠️ May lose |
| v4_graph_edges | ✅ Correct | ⚠️ May need rotation | ✅ Yes |
| v5_reexport | ✅ Correct | ✅ Correct | ⚠️ May lose |
| v6_scene_transform | ❌ Stacked | ✅ Correct | ✅ Yes |

---

## Recommended Approach After Testing

Based on the test results, the winning variant will likely be:
- **v2 or v4** for correct switch positions
- Combined with **v6** rotation approach if PCB orientation is still wrong

The final implementation will combine the best approaches:

```python
# 1. Load the PCB scene
left_pcb_scene = trimesh.load(LEFT_PCB_GLB)

# 2. Apply rotation to the entire scene (if needed)
rotation = trimesh.transformations.rotation_matrix(angle, axis)
left_pcb_scene.apply_transform(rotation)

# 3. Add geometries with their transforms from the graph
for node_name, geometry in left_pcb_scene.geometry.items():
    transform = left_pcb_scene.graph.get(node_name)[0]
    if transform is not None:
        transformed = geometry.copy()
        transformed.apply_transform(transform)
        scene.add_geometry(transformed, ...)
```

---

## Files to Create

1. `create_full_3d_visual_v1_baseline.py`
2. `create_full_3d_visual_v2_graph_transforms.py`
3. `create_full_3d_visual_v3_scene_merge.py`
4. `create_full_3d_visual_v4_graph_edges.py`
5. `create_full_3d_visual_v5_reexport.py`
6. `create_full_3d_visual_v6_scene_transform.py`

## Files to Modify

1. `.github/workflows/build.yaml` - Add step to run all variants

---

## Notes

- Each variant outputs to a different file: `combined_scene_v1.glb`, `combined_scene_v2.glb`, etc.
- This allows testing all approaches in a single push
- The best variant will be used as the basis for the final implementation
- Materials/colors may be lost in some variants - this is acceptable for testing purposes

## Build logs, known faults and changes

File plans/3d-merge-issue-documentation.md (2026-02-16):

# 3D Model Merge Issue Documentation

## Original Problem

**Issue:** The `create_full_3d_visual.py` script produces an invalid unified 3D scene where:
1. All switches are stacked in a single location (not at their correct PCB positions)
2. The PCB is oriented differently than the rest of the 3D models (case, cover, tenting, palm rest)

**Root Cause:** The script iterates over `scene.geometry.items()` which returns raw geometries **without their transforms**. In trimesh, transforms are stored in `scene.graph`, not in geometry objects.

## Input Files

- **Left PCB GLB:** `./filtered-output/pcbs/3d/left_pcb-3d.glb` (contains ~157 nodes with proper transforms)
- **Case STL:** `./filtered-output/cases/case.stl`
- **Cover STL:** `./filtered-output/cases/l_cover.stl`
- **Tenting STL:** `./filtered-output/cases/tenting_system.stl`
- **Palm Rest STL:** `./filtered-output/palmrest/palm_rest.stl`

## Test Variants Created

### v1_baseline (Original/Broken)
**File:** `create_full_3d_visual_v1_baseline.py`

**Approach:** Iterates over `scene.geometry.items()` without transforms.

**Result:** BROKEN - switches stacked at origin, PCB orientation wrong.

---

### v2_graph_transforms
**File:** `create_full_3d_visual_v2_graph_transforms.py`

**Approach:** Uses `scene.graph.get(node_name)` to get transforms, then applies them with `geometry.apply_transform()`.

**Result:** Position/orientation CORRECT, BUT objects are split into fragments (e.g., a keycap becomes separate top/bottom/side pieces).

**Feedback:** "elements were split into the fragments that compose them"

---

### v3_scene_merge
**File:** `create_full_3d_visual_v3_scene_merge.py`

**Approach:** Uses `scene.to_mesh()` to bake transforms into vertices, then adds the merged mesh.

**Result:** Position/orientation CORRECT, BUT all objects merged into ONE object (loses S25, HS8, K8 structure).

**Feedback:** "lost object differentiation entirely"

---

### v4_graph_edges
**File:** `create_full_3d_visual_v4_graph_edges.py`

**Approach:** Iterates over `scene.graph.edges()` to get transforms, applies with `geometry.apply_transform()`.

**Result:** Same as v2 - position correct but objects fragmented.

---

### v5_reexport
**File:** `create_full_3d_visual_v5_reexport.py`

**Approach:** Exports PCB scene to temp GLB, reimports, then adds STL meshes.

**Result:** Same as v3 - correct position but merged into one object.

---

### v6_scene_transform
**File:** `create_full_3d_visual_v6_scene_transform.py`

**Approach:** Applies scene-level transform to all geometries, then uses `to_mesh()`.

**Result:** PCB orientation NOT fixed.

---

### v7_preserve_structure
**File:** `create_full_3d_visual_v7_preserve_structure.py`

**Approach:** Uses `scene.add_geometry(geometry, transform=transform_matrix)` to set transforms in scene graph without modifying geometries.

**Result:** Same as v2/v4 - objects fragmented.

**Feedback:** "same issue as 4 and 2, the elements were split into fragments"

---

### v8_copy_graph
**File:** `create_full_3d_visual_v8_copy_graph.py`

**Approach:** Copies scene graph structure directly using `scene.graph.update()`.

**Result:** Same as v2/v4/v7 - objects fragmented.

---

### v9_scene_add
**File:** `create_full_3d_visual_v9_scene_add.py`

**Approach:** Uses trimesh's `scene + scene` operator to merge scenes.

**Result:** Same issue - objects fragmented.

---

### v10_pygltflib
**File:** `create_full_3d_visual_v10_pygltflib.py`

**Approach:** Uses pygltflib to load and re-export the GLB directly.

**Result:** PCB structure PRESERVED (switches at correct positions with correct names), BUT STL models not included.

**Feedback:** "v10 did actually load the object successfully but it didnt include any of the 3d models that are not part of the left pcb"

---

### v11_hybrid
**File:** `create_full_3d_visual_v11_hybrid.py`

**Approach:** Uses pygltflib for PCB GLB (preserves structure), trimesh to create STL GLB, then merges both.

**Result:** FAILED - issues with buffer manipulation.

---

## Summary of Feedback

| Variant | Position | Orientation | Object Structure | Notes |
|---|---|---|---|---|
| v1 | ❌ | ❌ | ❌ | Original broken code |
| v2 | ✅ | ✅ | ❌ | Objects fragmented |
| v3 | ✅ | ✅ | ❌ | All merged into one |
| v4 | ✅ | ✅ | ❌ | Objects fragmented |
| v5 | ✅ | ✅ | ❌ | All merged into one |
| v6 | ❌ | ❌ | ❌ | PCB orientation wrong |
| v7 | ✅ | ✅ | ❌ | Objects fragmented |
| v8 | ✅ | ✅ | ❌ | Objects fragmented |
| v9 | ✅ | ✅ | ❌ | Objects fragmented |
| v10 | ✅ | ✅ | ✅ | STL models missing |
| v11 | ❌ | ❌ | ❌ | Buffer merge failed |

## Key Insight

The PCB GLB file (from KiCad) has a proper scene graph where each component (S25 switch, HS8 hotswap, K8 keycap) is a named node with its own transform. When we extract geometries with `scene.geometry.items()`, we lose this structure.

**v10 showed that pygltflib correctly preserves this structure** - the issue is adding the STL models while maintaining the structure.

## Next Steps for New Task

1. **Build on v10's success:** v10 correctly preserved the PCB structure using pygltflib
2. **Focus on STL merging:** The challenge is adding STL models (case, cover, tenting, palm rest) to the GLB while preserving the PCB's scene graph structure
3. **Alternative approaches to try:**
   - Use Blender's Python API for GLB manipulation
   - Use a different glTF library with better merge capabilities
   - Export STL models as separate GLB files and use a GLB viewer that supports multiple files
   - Create a custom solution that manually constructs the glTF JSON structure

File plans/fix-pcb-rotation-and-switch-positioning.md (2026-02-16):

# Plan: Fix PCB Rotation and Switch Positioning in Unified 3D Model

## Problem Analysis

### Root Cause Identified

The issue is in [`create_full_3d_visual.py`](../create_full_3d_visual.py:28-34):

```python
# Load PCB 3D models (GLB format - already contains all components with materials)
# Use scene mode to preserve the structure, then extract geometry
left_pcb_scene = trimesh.load(LEFT_PCB_GLB)
if isinstance(left_pcb_scene, trimesh.Scene):
    left_pcb_mesh = trimesh.util.concatenate(list(left_pcb_scene.geometry.values()))
else:
    left_pcb_mesh = left_pcb_scene
```

**The problem:** When the GLB file is loaded as a `trimesh.Scene`, it contains:
- Multiple geometries (PCB board, switches, components)
- Node transforms (position, rotation, scale) for each geometry

By calling `trimesh.util.concatenate(list(left_pcb_scene.geometry.values()))`, we:
1. **Lose all node transforms** - Each geometry is concatenated into a single mesh at origin (0,0,0)
2. **Lose the scene hierarchy** - All components become one flat mesh
3. **Cause switches to merge** - Without proper transforms, switches overlap at the same position
4. **Lose PCB orientation** - The rotation transform that makes the PCB horizontal is discarded

### Why the Original GLB Files Are Correct

The KiCad-generated GLB files (`left_pcb-3d.glb`, `right_pcb-3d.glb`) contain:
- Proper scene graph with nodes
- Correct transforms for each component
- Proper orientation (PCB is horizontal)
- Switches positioned correctly at their actual locations

## Solution Design

### Approach: Preserve Scene Structure Instead of Concatenating

Instead of concatenating all geometries into one mesh, we should:
1. Keep the GLB scene structure intact
2. Apply the scene's transforms to each geometry
3. Add each transformed geometry to the combined scene individually
4. **Phase 1:** Test without rotation to see the baseline orientation
5. **Phase 2:** Apply rotation if needed based on Phase 1 results

### Implementation Strategy

#### Option 1: Add Scene to Scene (Recommended)
Use trimesh's ability to merge scenes while preserving transforms:

```python
# Load PCB as scene
left_pcb_scene = trimesh.load(LEFT_PCB_GLB)

if isinstance(left_pcb_scene, trimesh.Scene):
    # Phase 1: Add without rotation first to see baseline orientation
    # Phase 2: Apply rotation if needed (see below)
    
    # Merge the PCB scene into the combined scene
    for node_name, geometry in left_pcb_scene.geometry.items():
        scene.add_geometry(
            geometry,
            node_name=f"Left_PCB_{node_name}",
            geom_name=f"Left_PCB_{node_name}"
        )
```

#### Option 2: Apply Transforms Before Concatenating
For each geometry in the scene, apply its node transform before concatenating:

```python
left_pcb_scene = trimesh.load(LEFT_PCB_GLB)
if isinstance(left_pcb_scene, trimesh.Scene):
    # Get all geometries with their transforms
    transformed_geometries = []
    for node_name, geometry in left_pcb_scene.geometry.items():
        # Get the node transform for this geometry
        node = left_pcb_scene.graph.get(node_name)
        if node is not None:
            transform = left_pcb_scene.graph.get_transform(node_name)
            geometry = geometry.apply_transform(transform)
        transformed_geometries.append(geometry)
    
    # Now concatenate with all transforms applied
    left_pcb_mesh = trimesh.util.concatenate(transformed_geometries)
```

### Recommended Approach: Option 1 (Two-Phase)

**Advantages:**
- Preserves the scene hierarchy and component names
- Maintains materials and colors from GLB
- Easier to debug (can inspect individual components)
- More flexible for future modifications
- Better performance (no need to concatenate large meshes)
- **Two-phase approach allows testing before applying rotation**

## Implementation Steps

### Phase 1: Modify `create_full_3d_visual.py` (No Rotation)

Update the PCB loading section to preserve scene structure **without** applying rotation:

```python
# Load PCB 3D models (GLB format - already contains all components with materials)
left_pcb_scene = trimesh.load(LEFT_PCB_GLB)
if isinstance(left_pcb_scene, trimesh.Scene):
    # Add each geometry from the PCB scene to the combined scene
    # This preserves all transforms from the original GLB file
    for node_name, geometry in left_pcb_scene.geometry.items():
        scene.add_geometry(
            geometry,
            node_name=f"Left_PCB_{node_name}",
            geom_name=f"Left_PCB_{node_name}"
        )
else:
    # Fallback for non-scene files
    scene.add_geometry(
        left_pcb_scene,
        node_name="Left_PCB",
        geom_name="Left_PCB"
    )
```

### Phase 2: Test Phase 1 Changes

1. Run the updated script
2. Verify that:
   - Switches are positioned correctly (not merged together)
   - All components maintain their proper spacing
   - Materials and colors are preserved
3. Check the PCB orientation:
   - Is it horizontal or vertical?
   - Does it match the original `left_pcb-3d.glb` orientation?

### Phase 3: Add Rotation (If Needed)

**Based on Phase 2 results**, if the PCB orientation is still incorrect, add rotation:

```python
# Load PCB 3D models (GLB format - already contains all components with materials)
left_pcb_scene = trimesh.load(LEFT_PCB_GLB)
if isinstance(left_pcb_scene, trimesh.Scene):
    # Apply rotation to the entire PCB scene
    # Adjust angle and axis based on Phase 2 testing
    rotation_matrix = trimesh.transformations.rotation_matrix(
        angle=np.pi,  # 180 degrees (adjust as needed)
        direction=[1, 0, 0]  # X-axis (adjust as needed)
    )
    left_pcb_scene.apply_transform(rotation_matrix)
    
    # Add each geometry from the PCB scene to the combined scene
    for node_name, geometry in left_pcb_scene.geometry.items():
        scene.add_geometry(
            geometry,
            node_name=f"Left_PCB_{node_name}",
            geom_name=f"Left_PCB_{node_name}"
        )
else:
    # Fallback for non-scene files
    scene.add_geometry(
        left_pcb_scene,
        node_name="Left_PCB",
        geom_name="Left_PCB"
    )
```

**Possible rotation adjustments based on Phase 2 results:**
- If PCB is vertical and needs to be horizontal: Try 180° around X-axis or 90° around Y-axis
- If PCB is flipped: Try 180° around Z-axis
- If PCB is rotated: Try 90° around X-axis

## Alternative Considerations

### If Phase 1 Shows Switches Are Still Merged

If switches are still overlapping after preserving scene structure, check:
1. Whether the GLB file itself has incorrect transforms
2. Whether the `fix_glb_scale.py` script is affecting transforms
3. Whether the KiCad 3D model footprints have correct positions
4. Try Option 2 (apply transforms before concatenating) as an alternative

### If Rotation is Still Incorrect After Phase 3

If the PCB orientation is still wrong after applying the rotation, we may need to:

1. **Inspect the original GLB file** to understand its coordinate system
2. **Check the KiCad export settings** to see if there's an option to adjust orientation
3. **Apply a different rotation** based on the actual orientation needed
4. **Try multiple rotation combinations** (e.g., rotate around X then Y)

## Dependencies

- `trimesh` - Already in use
- `numpy` - Already in use (for rotation matrices in Phase 3)

## Files to Modify

1. [`create_full_3d_visual.py`](../create_full_3d_visual.py) - Main implementation (Phase 1 and Phase 3)
2. No changes needed to [`fix_glb_scale.py`](../fix_glb_scale.py) - Scale fixing is separate from orientation

## Expected Outcome

### After Phase 1:
- ✅ Switches will be positioned correctly (not merged)
- ✅ All components maintain proper spacing
- ✅ Scene hierarchy is preserved
- ✅ Materials and colors are maintained
- ⏳ PCB orientation will be visible (may need Phase 3 adjustment)

### After Phase 3 (if needed):
- ✅ PCB will be horizontal (matching other models)
- ✅ All Phase 1 benefits maintained
- ✅ The unified 3D model will be accurate and usable

## Testing Checklist

### Phase 1 Testing:
- [ ] Run `python3 create_full_3d_visual.py`
- [ ] Open `filtered-output/combined_scene.glb` in a 3D viewer
- [ ] Verify switches are not merged
- [ ] Verify all components are visible and positioned correctly
- [ ] Verify materials and colors look correct
- [ ] Compare with original `left_pcb-3d.glb` to ensure consistency
- [ ] Note the PCB orientation (horizontal/vertical, any rotation needed)

### Phase 3 Testing (if needed):
- [ ] Add rotation code based on Phase 1 observations
- [ ] Run `python3 create_full_3d_visual.py` again
- [ ] Open `filtered-output/combined_scene.glb` in a 3D viewer
- [ ] Verify PCB is horizontal
- [ ] Verify all Phase 1 benefits are maintained

## Notes

- **Two-phase approach**: First fix the scene structure (Phase 1), then adjust orientation (Phase 3)
- This allows us to see the baseline behavior before applying any rotation
- The rotation angle and axis will be determined based on Phase 1 results
- The solution preserves the scene structure, making it easier to debug and modify
- This approach is more maintainable than concatenating geometries
- If Phase 1 already produces correct orientation, Phase 3 may not be needed

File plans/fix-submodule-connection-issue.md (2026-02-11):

# Fix Submodule Connection Issue

## Problem Summary

The GitHub Actions workflow is failing when trying to checkout the submodule `ergogen/footprints/ceoloide`. The error indicates that a specific commit (`0de6129caa0437b600a85eff43ebfc111cd6f11d`) cannot be found in the remote repository.

## Root Cause Analysis

### Current State

1. **Submodule Configuration** ([`.gitmodules`](.gitmodules:1)):
   ```git
   [submodule "ergogen/footprints/ceoloide"]
       path = ergogen/footprints/ceoloide
       url = https://github.com/Happily-Coding/ergogen-footprints.git
   ```

2. **Submodule Status**:
   ```
   0de6129caa0437b600a85eff43ebfc111cd6f11d ergogen/footprints/ceoloide (v0.0.3-11-g0de6129)
   ```
   - The submodule is pointing to commit `0de6129`
   - This is 11 commits ahead of tag `v0.0.3`
   - The commit is on a detached HEAD state

3. **Local Commits**:
   ```
   0de6129 Add 3d model display
   b685279 Added pos file to switch_choc_v1_v2
   5dc613f Added offsets (poorly named)
   49fb59d Fix footprint module name
   b33bf19 Fix footprint module name
   ```

4. **Remote Repository State**:
   - **Origin** (Happily-Coding/ergogen-footprints):
     - `feature/sweepyway-customizations` branch exists at commit `b685279`
     - Commit `0de6129` does NOT exist in this remote
   - **Upstream** (ceoloide/ergogen-footprints):
     - Main branch at commit `54a23cc`
     - Latest tag is `v0.0.9`
     - Commit `0de6129` does NOT exist in this remote

### The Issue

The submodule is referencing a commit (`0de6129`) that:
- Exists locally in the working directory
- Does NOT exist in the remote `https://github.com/Happily-Coding/ergogen-footprints.git`
- Was never pushed to the remote repository

When GitHub Actions tries to checkout the submodule, it fails because:
```
fatal: remote error: upload-pack: not our ref 0de6129caa0437b600a85eff43ebfc111cd6f11d
fatal: Fetched in submodule path 'ergogen/footprints/ceoloide', but it did not contain 0de6129caa0437b600a85eff43ebfc111cd6f11d. Direct fetching of that commit failed.
```

## Diagnostic Steps

### Step 1: Verify the issue
```bash
git submodule status
```
Expected output shows the problematic commit reference.

### Step 2: Check remote availability
```bash
cd ergogen/footprints/ceoloide
git ls-remote origin | grep 0de6129
```
Expected: No output (commit doesn't exist in remote)

### Step 3: Check local vs remote
```bash
cd ergogen/footprints/ceoloide
git log --oneline -5
git ls-remote origin
```
This shows that the local commits are ahead of the remote.

## Proposed Solutions

### Solution 1: Push Local Changes to Remote Fork (Recommended)

**Prerequisites:**
- Write access to `https://github.com/Happily-Coding/ergogen-footprints.git`

**Steps:**
1. Push the local commits to the remote repository
2. Update the submodule reference in the main repository

```bash
# Navigate to the submodule
cd ergogen/footprints/ceoloide

# Push the local commits to the remote
git push origin HEAD:feature/sweepyway-customizations

# Navigate back to the main repository
cd ../..

# Update the submodule reference
git add ergogen/footprints/ceoloide
git commit -m "Update submodule to latest commit"
git push
```

**Pros:**
- Preserves all customizations
- Maintains the current state of the project
- No loss of work

**Cons:**
- Requires write access to the remote repository
- Requires pushing potentially unreviewed commits

---

### Solution 2: Switch to Existing Remote Branch

**Steps:**
1. Reset the submodule to the remote branch tip
2. Commit the change

```bash
# Navigate to the submodule
cd ergogen/footprints/ceoloide

# Reset to the remote branch tip
git fetch origin
git checkout feature/sweepyway-customizations
git reset --hard origin/feature/sweepyway-customizations

# Navigate back to the main repository
cd ../..

# Update the submodule reference
git add ergogen/footprints/ceoloide
git commit -m "Reset submodule to remote branch tip"
git push
```

**Pros:**
- Uses an existing remote branch
- Preserves most customizations (up to commit `b685279`)
- No write access required to create new commits

**Cons:**
- Loses 1 commit (the "Add 3d model display" commit)
- May require recreating the lost commit

---

### Solution 3: Switch to a Tag (Cleanest but Loses Customizations)

**Steps:**
1. Reset the submodule to an existing tag
2. Commit the change

```bash
# Navigate to the submodule
cd ergogen/footprints/ceoloide

# Reset to a specific tag
git fetch origin
git checkout v0.0.3

# Navigate back to the main repository
cd ../..

# Update the submodule reference
git add ergogen/footprints/ceoloide
git commit -m "Reset submodule to v0.0.3 tag"
git push
```

**Pros:**
- Uses a stable, released version
- No customizations to maintain
- Simple and reliable

**Cons:**
- Loses ALL customizations (12 commits)
- May require recreating all customizations
- May break the build if customizations are required

---

### Solution 4: Merge with Upstream and Push

**Steps:**
1. Merge upstream changes into the local branch
2. Push the merged branch to the remote

```bash
# Navigate to the submodule
cd ergogen/footprints/ceoloide

# Create a local branch from the current state
git checkout -b feature/sweepyway-customizations

# Fetch upstream
git fetch upstream

# Merge upstream main into the branch
git merge upstream/main

# Push to the remote
git push origin feature/sweepyway-customizations

# Navigate back to the main repository
cd ../..

# Update the submodule reference
git add ergogen/footprints/ceoloide
git commit -m "Update submodule to merged branch"
git push
```

**Pros:**
- Incorporates upstream changes
- Preserves customizations
- Keeps the branch up to date

**Cons:**
- Requires write access to the remote repository
- May create merge conflicts
- More complex process

---

## Recommended Action Plan

### Phase 1: Assessment
1. Verify which customizations are critical for the project
2. Check if you have write access to `Happily-Coding/ergogen-footprints`
3. Determine if the lost commit(s) can be recreated if needed

### Phase 2: Implementation
Based on the assessment, choose one of the solutions above:
- **If you have write access and want to preserve everything**: Use Solution 1
- **If you have write access and want to stay current**: Use Solution 4
- **If you don't have write access and can lose 1 commit**: Use Solution 2
- **If you don't have write access and can lose all customizations**: Use Solution 3

### Phase 3: Verification
1. After applying the fix, run the GitHub Actions workflow
2. Verify that the submodule checkout succeeds
3. Verify that the build completes successfully
4. Verify that all generated files are correct

## Workflow Configuration

The current workflow configuration in [`.github/workflows/build.yaml`](.github/workflows/build.yaml:22) is correct:

```yaml
- name: Checkout
  uses: actions/checkout@v4
  with:
    submodules: true
```

This configuration is already set up to handle submodules correctly. The issue is purely with the submodule reference pointing to a non-existent remote commit.

## Additional Considerations

### Future Prevention
To prevent this issue in the future:
1. Always push submodule changes before updating the main repository
2. Consider using tags instead of commit SHAs for submodule references
3. Implement a pre-commit hook to verify submodule references
4. Consider using a CI check to verify submodule references are valid

### Alternative Approach: Remove Submodule
If the submodule is not actively maintained or the customizations are minimal, consider:
1. Removing the submodule reference
2. Copying the necessary files directly into the repository
3. Maintaining them as part of the main project

This eliminates the submodule complexity entirely.

## Mermaid Diagram

```mermaid
flowchart TD
    A[GitHub Actions Starts] --> B[Checkout Main Repo]
    B --> C[Checkout Submodule]
    C --> D{Commit Exists in Remote?}
    D -->|Yes| E[Submodule Checkout Success]
    D -->|No| F[Error: Commit Not Found]
    E --> G[Build Continues]
    F --> H[Build Fails]
    
    I[Current State] --> J[Commit 0de6129 exists locally]
    J --> K[Commit 0de6129 NOT in remote]
    K --> L[Actions tries to fetch 0de6129]
    L --> F
    
    M[Solution 1: Push Changes] --> N[Push 0de6129 to remote]
    N --> D
    
    O[Solution 2: Reset to Branch] --> P[Reset to b685279]
    P --> Q[Update submodule ref]
    Q --> D
    
    R[Solution 3: Reset to Tag] --> S[Reset to v0.0.3]
    S --> T[Update submodule ref]
    T --> D
    
    U[Solution 4: Merge & Push] --> V[Merge upstream changes]
    V --> W[Push merged branch]
    W --> D
```

## Next Steps

1. Review this plan and decide which solution to implement
2. Verify write access to the remote repository if needed
3. Implement the chosen solution
4. Test the GitHub Actions workflow
5. Verify the build output is correct

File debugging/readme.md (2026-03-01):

paths may need changing since i moved them away from the main folder

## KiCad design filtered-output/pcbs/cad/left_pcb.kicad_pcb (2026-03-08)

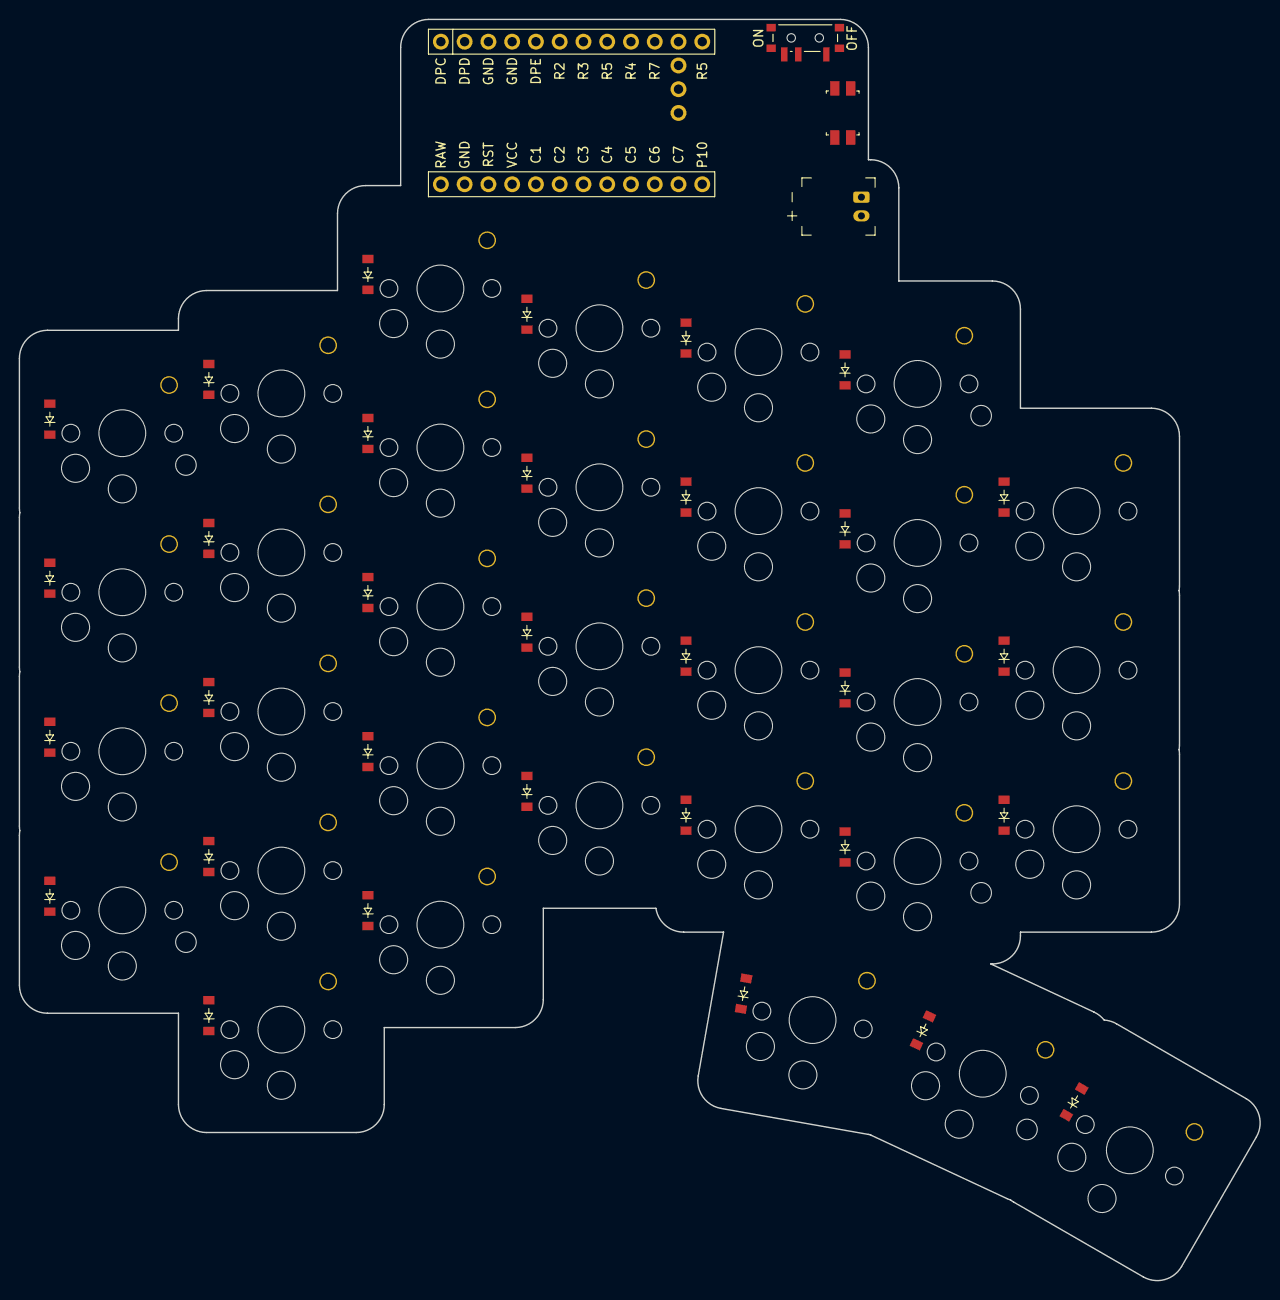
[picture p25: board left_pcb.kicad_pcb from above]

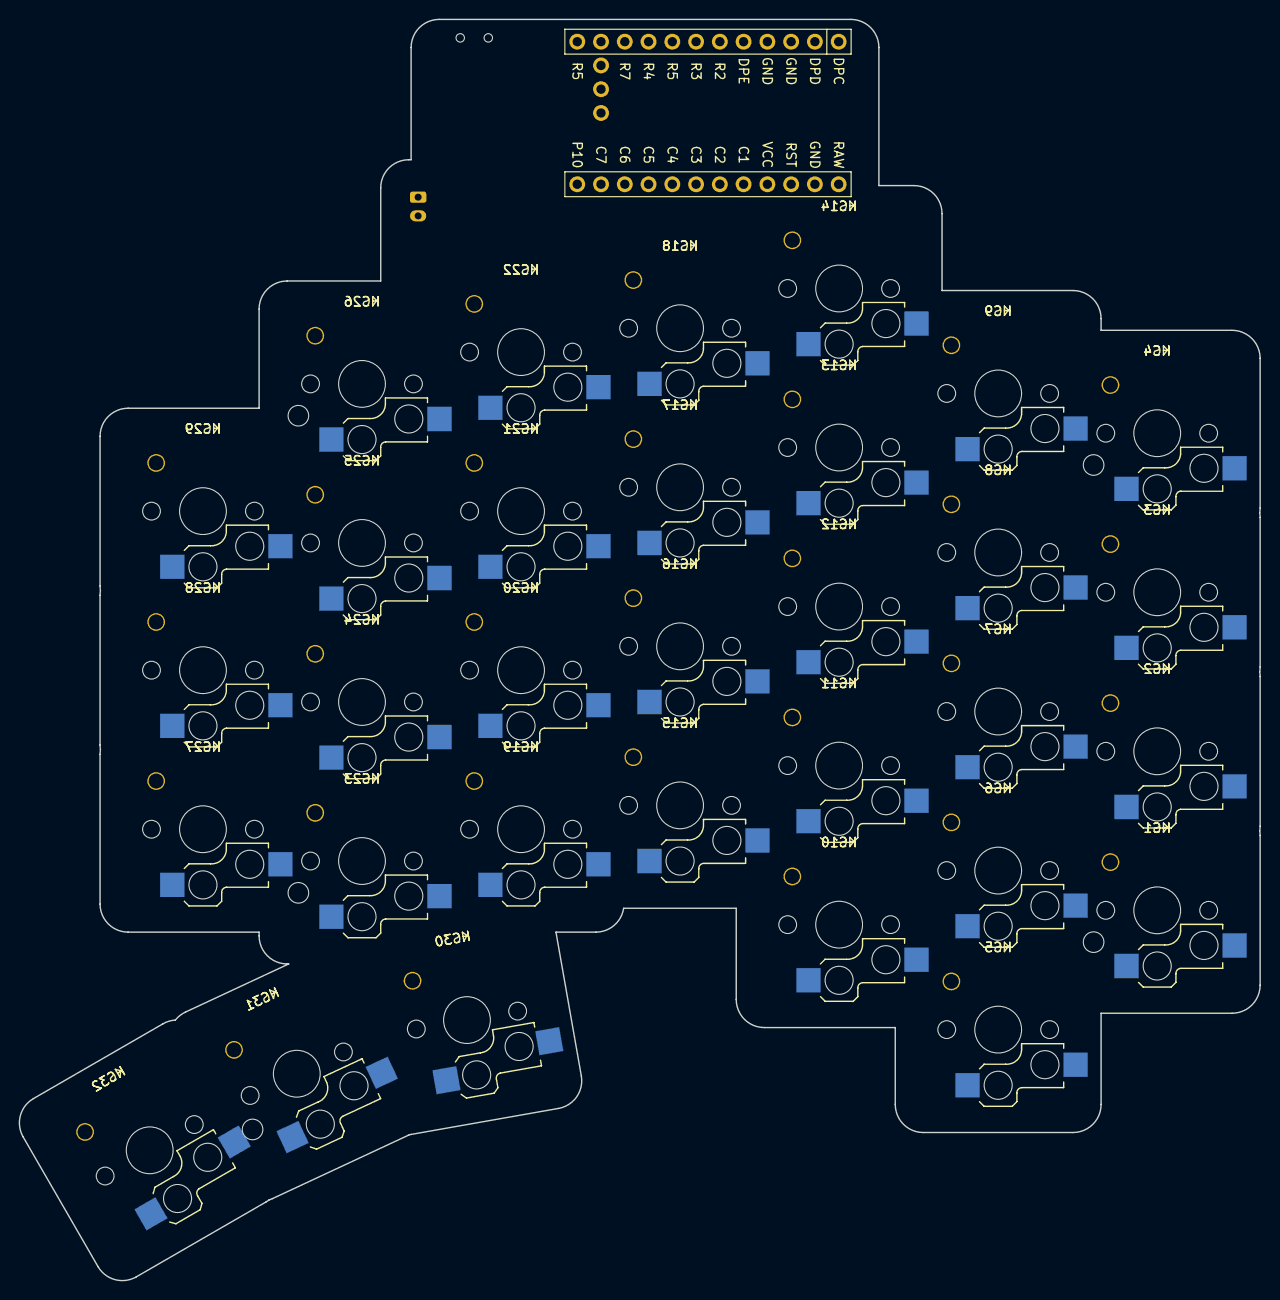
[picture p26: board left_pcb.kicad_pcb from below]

Board: 2 copper layers, 132.6 x 134.8 mm, 154 parts (96 on the bottom side), 48 nets, no tracks yet.

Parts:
D1, D2, D3, D4, D5, D6, D7, D8, D9, D10, D11, D12, D13, D14, D15, D16, D17, D18, D19, D20, D21, D22, D23, D24, D25, D26, D27, D28, D29, D30, D31, D32: diode_tht_sod123
H1, H2: header-preview_nano
HS1, HS2, HS3, HS4, HS5, HS6, HS7, HS8, HS9, HS10, HS11, HS12, HS13, HS14, HS15, HS16, HS17, HS18, HS19, HS20, HS21, HS22, HS23, HS24, HS25, HS26, HS27, HS28, HS29, HS30, HS31, HS32: hs-socket-fab-preview_choc_v1_v2
JST1: battery_connector_jst_ph_2
KC1, KC2, KC3, KC4, KC5, KC6, KC7, KC8, KC9, KC10, KC11, KC12, KC13, KC14, KC15, KC16, KC17, KC18, KC19, KC20, KC21, KC22, KC23, KC24, KC25, KC26, KC27, KC28, KC29, KC30, KC31, KC32: keycap-fab-preview_choc_v1_v2
MCU1: mcu_nice_nano
MH1, MH2, MH3, MH4, MH5: mounting_hole_npth
PWR1: power_switch_smd_side
RST1: reset_switch_smd_side
S1, S2, S3, S4, S5, S6, S7, S8, S9, S10, S11, S12, S13, S14, S15, S16, S17, S18, S19, S20, S21, S22, S23, S24, S25, S26, S27, S28, S29, S30, S31, S32: choc_v1_v2
SC1, SC2, SC3, SC4, SC5: screw-preview-top
SC6, SC7, SC8, SC9, SC10: screw-preview-bottom
ST1, ST2, ST3, ST4, ST5: standoff-preview

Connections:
BAT_P: JST1.2, PWR1.3
C1: MCU1.20, S1.2, S2.2, S3.2, S4.2
C2: MCU1.19, S5.2, S6.2, S7.2, S8.2, S9.2
C3: MCU1.18, S10.2, S11.2, S12.2, S13.2, S14.2
C4: MCU1.17, S15.2, S16.2, S17.2, S18.2
C5: MCU1.16, S19.2, S20.2, S21.2, S22.2, S30.2
C6: MCU1.15, S23.2, S24.2, S25.2, S26.2, S31.2
C7: MCU1.14, S27.2, S28.2, S29.2, S32.2
GND: JST1.1, MCU1.3, MCU1.4, MCU1.23, RST1.1, RST1.3
R1: D4.1, D9.1, D14.1, D18.1, D22.1, D26.1
R2: D3.1, D8.1, D13.1, D17.1, D21.1, D25.1, D29.1, MCU1.6
R3: D2.1, D7.1, D12.1, D16.1, D20.1, D24.1, D28.1, MCU1.7
R4: D1.1, D6.1, D11.1, D15.1, D19.1, D23.1, D27.1, MCU1.9
R5: D5.1, D10.1, D30.1, D31.1, D32.1, MCU1.8, MCU1.12
RAW: MCU1.24, PWR1.2
RST: MCU1.22, RST1.2, RST1.4
col1_row1: D4.2, S4.1
col1_row2: D3.2, S3.1
col1_row3: D2.2, S2.1
col1_row4: D1.2, S1.1
col1_thumb_row_1: D30.2, S30.1
col2_row1: D9.2, S9.1
col2_row2: D8.2, S8.1
col2_row3: D7.2, S7.1
col2_row4: D6.2, S6.1
col2_row5: D5.2, S5.1
col2_thumb_row_1: D31.2, S31.1
col3_row1: D14.2, S14.1
col3_row2: D13.2, S13.1
col3_row3: D12.2, S12.1
col3_row4: D11.2, S11.1
col3_row5: D10.2, S10.1
col3_thumb_row_1: D32.2, S32.1
col4_row1: D18.2, S18.1
col4_row2: D17.2, S17.1
col4_row3: D16.2, S16.1
col4_row4: D15.2, S15.1
col5_row1: D22.2, S22.1
col5_row2: D21.2, S21.1
col5_row3: D20.2, S20.1
col5_row4: D19.2, S19.1
col6_row1: D26.2, S26.1
col6_row2: D25.2, S25.1
col6_row3: D24.2, S24.1
col6_row4: D23.2, S23.1
col7_row2: D29.2, S29.1
col7_row3: D28.2, S28.1
col7_row4: D27.2, S27.1

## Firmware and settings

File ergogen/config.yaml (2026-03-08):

meta:
  engine: 4.1.0
  name: SweepyWay
  version: &kb_version v0.2
  author: Happily-Coding
  url: &kb_url https://github.com/Happily-Coding/SweepyWay/

# Define presets that can be selected in the units section to achieve your desired layout.
presets:
  choc_spacing:
    # Standard Choc spacing, compatible with MBK keycaps which are 16.5 x 17.5
    kx: 17 # spacing between keys (X-axis) 
    ky: 18 # spacing between key (Y-axis)  # Will be overwritten by cfx spacing if you use cfx in units extends
    keycap_x_1u: 17.5
    keycap_y_1u: 16.5 # Will be overwritten by cfx spacing if you use cfx in units extends

    px: 5 #10 #3.5 #How much to pad horizontally
    py: 5 #10 #3.5 #how much to pad vertically
    plate_kx: 13.8 # key cutout hole width (cherry, choc v2: 14, choc v1: 13.8)
    plate_ky: 13.8 # key cutout hole height (cherry, choc v2: 14, choc v1: 13.8)
    vertical_diode_shift: 1.5 # How much to shift to avoid overlap
    horizontal_diode_shift: -0.5 plate_kx - 0.85
    diode_rotation: 0
    #diode_rotation: -180 # Diode rotation
    #switch_rotation: 180 # Hotswap south, led north
    
  cfx_spacing: # a preset that can be chosen in the units section, to create a pcb made for chosfox keycaps spacing, which is tighter vertically, allowing you to easily reach the number keys.
    # CFX 1u are 16.5x16.5 keys for a tighter 17x17 matrix.
    $extends: presets.choc_spacing
    kx: 17 # spacing between keys (X-axis) 
    ky: 17 # spacing between keys(Y-axis)
    keycap_x_1u: 16.5
  #pcb_to_case_wall_tolerance: 0.25 <-- asi era ref, debe ser ultra exagerado lo mio.

units:
  $extends: presets.cfx_spacing

  screw_radius: 1.1 # M2 screws
  screw_diameter: screw_radius * 2
  screw_head_radius: 2.05
  screw_head_diameter: screw_head_radius * 2
  spacer_radius: 2.15 # M2 standoffs
  spacer_diameter: spacer_radius * 2
  fillet_radius: 0.5
  via_size: 0.56 # JLCPCB min 0.56 | KiCad default 0.8
  via_drill: 0.3 # JLCPCB min 0.3 | KiCad default 0.4

  # Case variables
  case_wall_thickness: 1.2
  pcb_to_case_wall_tolerance: 0.25
  bottom_plate_thickness: 1.0
  top_plate_thickness: 1.6
  internal_distance_between_plates: 4
  case_border_height: 16 # added by me, in a quick search soffle choic was arround 17 theoretically
  case_bottom_thickness: 3
  #TODO: aplicar offset adicional por screw minimo. porque no va a entrar asi , hay que buscar a la esquina posta. si no choca con switch.
  screw_offset_x: 0.4 kx #How much to move the screw from the reference point. To avoid landing inside the switches
  screw_offset_y: -0.2 ky #how much to move the screw from the referene point
  controller_area_height: 5 #How tall relative to the switch plate the controller area cover should be at
  controller_area_wall_thickness: 2 #How thick (wide) the wall of the controller area should be
  controller_area_cover_thickness: 1.6 #How thick (tall) the cover should be 

  # Font units
  font_x: 1
  font_y: 1
  font_xo: 0.5 font_x
  font_yo: 0.5 * font_y

  # Nice Nano
  mcu_spacing_x: 2.72
  mcu_x: 17.78 + mcu_spacing_x
  mcu_y: 33.02
  mcu_xo: 0.5 * mcu_x
  mcu_yo: 0.5 * mcu_y  

  # Battery Connector
  batc_x: 4.3
  batc_y: 4.6
  batc_xo: 0.5 * batc_x
  batc_yo: 0.5 * batc_y

  # Battery Pads
  batp_x: 3.75
  batp_y: 2.5
  batp_xo: 0.5 * batp_x
  batp_yo: 0.5 * batp_y

  # Power Switch
  sw_power_x: 3.1
  sw_power_y: 8.3
  sw_power_xo: 0.5 * sw_power_x
  sw_power_yo: 0.5 * sw_power_y

  # Reset Switch
  sw_reset_x: 3.4
  sw_reset_y: 5
  sw_reset_xo: 0.5 * sw_reset_x
  sw_reset_yo: 0.5 * sw_reset_y

  #How much pcb to generate arround the center of the controller
  #Its better for it to be on the bigger side to ensure there are no gaps between it and the keyboard pcb area
  #As long as you also offset it with negative y it shouldnt be a problem
  controller_sorrounding_x: 50 
  controller_sorrounding_y: 30
  l_controller_area_x_shift: 8
  r_controller_area_x_shift: 8
  l_controller_area_y_shift: -5
  r_controller_area_y_shift: -5
  controller_center_y_shift: -2 #How much to move the center of the controller upward in y
  controller_area_roof_z_thickness: 2
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

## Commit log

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2023-05-04 Add ergogen output to GitHub
    [backplate.dxf, controller_overlay.dxf, corney_island.kicad_pcb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]
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2023-05-05 Fix OLED pad position
    [corney_island.kicad_pcb]
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2023-05-05 Remove vias from the PCB
    [corney_island.kicad_pcb]
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2023-05-10 Switch from sod-123w to diode to fix GH workflow
    [config.yaml]
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2023-05-11 Add additional outputs: images, routed PCB, gerber
    [corney_island.kicad_pcb, corney_island_routed.kicad_pcb]
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2023-05-11 Fix diode rotation (typo)
    [config.yaml]
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2023-05-11 Update outputs with additional plate files
    [backplate.kicad_pcb, controller_overlay.kicad_pcb, corney_island.kicad_pcb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]
2023-05-18 Add meta and preset to config.yaml
    [backplate.kicad_pcb, controller_overlay.kicad_pcb, corney_island.kicad_pcb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]
2023-05-20 Fix diode position
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2023-06-05 Fix key positions to exactly match the corne
    [backplate.dxf, backplate.kicad_pcb, controller_overlay.dxf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]
2023-06-05 Fix screw spacer holes to match the corne
    [corney_island.kicad_pcb, corney_island_routed.kicad_pcb, pcb.dxf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]
2023-06-05 Fix screw mounting holes positions
    [config.yaml]
2023-06-05 Fix MCU cover mounting holes position
    [backplate.dxf, backplate.kicad_pcb, controller_overlay.dxf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]
2023-06-06 Fix component positions to match the corne
    [corney_island.kicad_pcb, corney_island_routed.kicad_pcb]
2023-06-06 Update nets and diode positions
    [corney_island.kicad_pcb, corney_island_routed.kicad_pcb]
2023-06-06 Add per-key reversible LEDs
    [corney_island.kicad_pcb, corney_island_routed.kicad_pcb, pcb.dxf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]
2023-06-06 Switch to reversible TRRS jack
    [corney_island.kicad_pcb, corney_island_routed.kicad_pcb]
2023-06-06 Add LED and diode rotation, diode shift
    [corney_island.kicad_pcb, corney_island_routed.kicad_pcb]
2023-06-06 Fix missing diode rotation
    [corney_island.kicad_pcb, corney_island_routed.kicad_pcb]
2023-06-07 Fix LED silk screen
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2023-06-11 Revert to 128x32 F-only oled
    [config.yaml]
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2023-06-14 Add the option to flip the footprint
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2023-06-14 Fix pin order
2023-06-14 Update LED options and rotation
    [corney_island.kicad_pcb, corney_island_routed.kicad_pcb]
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2023-06-15 Fix wrong preset reference
    [config.yaml]
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2023-06-16 Fix screw position and simplify shift values
    [config.yaml]
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2023-07-24 Fix inner underglow LED position
    [backplate.dxf, backplate.kicad_pcb, corney_island.kicad_pcb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]
2023-07-24 Overhaul outlines making use of intersect
    [backplate.dxf, backplate.kicad_pcb, controller_overlay.dxf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]
2023-07-24 Change to relative measures for helper points
    [backplate.dxf, backplate.kicad_pcb, corney_island.kicad_pcb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]
2023-07-24 Add missing parametric measures
    [backplate.dxf, backplate.kicad_pcb, corney_island.kicad_pcb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]
2023-07-24 Fix keycap and preview outlines
    [preview.dxf]
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2023-08-27 Fix missing led net reference
    [config.yaml]
2023-08-27 Fix LED net order
    [config.yaml]
2023-09-11 Fix duplicate thru-hole pads in reversible config
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2023-09-26 Split diode position on F and B layers
    [corney_island.kicad_pcb, corney_island_routed.kicad_pcb]
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2023-09-30 Fix list of boardcs in GitHub Action
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2023-10-02 Switch to infused-kim nice-nano footprint
    [corney_island.kicad_pcb, corney_island_routed.kicad_pcb]
2023-10-03 Fix per-key LED rotation on MX switches
    [config.yaml]
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2023-10-11 Fix reset switch silk screen text size
    [config.yaml]
2023-10-11 Fix LED orientation, traces, keepout
2023-10-11 Update traces with correct clearance values
    [config.yaml]
2023-10-11 Update artifacts with latest unrouted build
    [corney_island.kicad_pcb]
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2023-10-12 Update artifacts with latest config + manual trace
    [corney_island.kicad_pcb, corney_island_manually_routed.kicad_pcb]
2023-10-12 Fix usage of old data net name for TRRS
    [corney_island.kicad_pcb]
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2023-10-12 Add JLCPCB production number text
    [corney_island.kicad_pcb, corney_island_manually_routed.kicad_pcb, test.kicad_pcb]
2023-10-13 Fix pin 1 and 2 of the TRRS footprint
    [corney_island_manually_routed.kicad_pcb]
2023-10-13 Add board name and version
    [corney_island_manually_routed.kicad_pcb]
2023-10-15 Add nets and defaults
    [corney_island.kicad_pcb]
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2023-10-15 Remove unused test PCB
    [test.kicad_pcb]
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2023-10-16 Switch routed board suffix to `_autorouted`
    [corney_island_autorouted.kicad_pcb]
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2023-10-17 Add expected errors to KiBot filters
2023-10-17 Update clearance and via rules for PWR/GND
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2023-10-17 Add partially routed PCB output
    [corney_island_mx_partially_routed.kicad_pcb]
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2023-10-19 Switch to kicad_default clearance to avoid error
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2023-10-23 Replace screw holes with spacer holes
    [config.yaml]
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2023-10-24 Fix wrong DIN / DOUT reference for underglow
    [config.yaml]
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2023-10-30 Remove partially routed board
    [corney_island_mx_partially_routed.kicad_pcb]
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2023-11-05 Invert diode X position for choc switches
    [config.yaml]
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2023-11-22 Fix on/off switch position for clearance violation
    [config.yaml]
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2023-11-26 Fix footprint reference text
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2023-11-30 Add wireless autoroute assets
    [corney_island_wireless_autorouted.kicad_pcb]
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2024-01-14 Fix pin polarity
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2024-01-15 Replace edge cut holes with footprint
    [config.yaml]
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2024-01-17 Make use of the correct power button
    [config.yaml]
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2024-01-18 Add option to invert switch behavior
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2024-01-18 Fix position and size of stabilizer hole for choc v2
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2024-01-19 Invert silkscreen labels so they are read correctly on the soldering side
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2024-02-26 Add 3D printed bottom case
    [corney_island_bottom_tray.stl, preview.dxf]
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2024-03-03 Add missing output for manually routed board
2024-03-30 Update TRRS footprint pinout and module
    [backplate.kicad_pcb, controller_overlay.kicad_pcb, corney_island.kicad_pcb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]
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2024-04-05 Update footprints library and artifacts
    [corney_island.kicad_pcb, corney_island_autorouted.kicad_pcb, corney_island_wireless.kicad_pcb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]
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2024-04-11 Slightly move the reset switch to avoid overlap with new display footprint
    [config.yaml]
2024-04-11 Switch to KiCad 8 PCB template and require Ergogen v4.1.0
    [backplate.kicad_pcb, controller_overlay.kicad_pcb, corney_island.kicad_pcb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]
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2024-05-29 Initial Typematrix from https://github.com/tbaumann/typematrix_split_ergogen/
    [backplate.dxf, backplate.kicad_pcb, controller_overlay.dxf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]
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2024-10-01 Move controller to the top
    [typematrix layup dimensions.ods]
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2025-06-30 Fixed right plate components placement, expanded padding heavily to try to generate a routable version of the pcb which to optimize later on fixed thumbcluster diode placement
    [config.yaml]
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2025-07-14 fixed a likely issue with the bom code
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2025-07-14 removed bom from jlpcb pos and correct jlpcb bom
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2025-08-17 Added palm rest experiments and begining of final code
    [hand_rest_extruded.stl, l_hand_rest_lofted.stl, l_hand_rest_lofted_solid.stl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]
2025-08-17 fixed palmrest name and added a palmrest creation stage to build.yaml
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2025-09-20 moved right side componets to the correct side
    [config.yaml]
2025-09-20 fixed usb outline not substracting
    [config.yaml]
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2026-01-31 added 3d models for parts
    [Choc_V1_Hotswap.step, Choc_V1_Keycap_MBK_White_1u.step, Choc_V1_Switch.step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]
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2026-01-31 moved 3d models and first working version (though they are incorrectly placed)
    [Choc_V1_Hotswap.step, Choc_V1_Keycap_MBK_White_1u.step, Choc_V1_Switch.step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]
2026-01-31 Added misisng switch, socket, keycap footprints and rotated them to the correct side of the pcb
    [config.yaml]
2026-01-31 Fixed the positioning of the switch 3d model
    [config.yaml]
2026-02-01 Added multiple 3d models for previsualizaiton
    [D_SOD-123.step, EVQ-PUC02K.stp, SSSS811101--3DModel-STEP-269445.STEP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]
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2026-02-01 ci: add pos file post-processing to build workflow
    Add steps to post-process KiBot-generated POS files for JLCPCB assembly.
    The post-processing script replaces footprint names with JLCPCB part
    numbers (e.g., switch_choc_v1_v2 → CPG135001S30). Processed files are
    copied to filtered-output directory for automatic deployment.
    This change enables automated generation of assembly-ready POS files,
    eliminating manual post-processing steps and ensuring consistent output
    for every build.
2026-02-06 Fix permission issues in workflow - add sudo to filtered-output operations
2026-02-06 Fix OpenJSCAD CLI - copy JSCAD files to filtered-output/cases
2026-02-06 Fix GLB assembly and STL export issues
2026-02-06 add examples and fix scaling of the glb
    [case.stl, cover.stl, palm_rest.stl]
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2026-02-07 Added a few missing details to the pcb export
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2026-02-07 Add 3dmodels for jstph
    [JSTPH2 S2B-PH-K-S(LF)(SN).STEP]
2026-02-07 renamed the files to prevent issues, fixed positioning
    [JSTPH2-S2B-PH-K-S-LF-SN.STEP]
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2026-02-13 Add pin header models
    [PinHeader_1x03_P2.54mm_Vertical.step, PinHeader_1x04_P2.54mm_Vertical.step, PinHeader_1x07_P2.54mm_Vertical.step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]
2026-02-13 Add alternative microcontroller models (without wrl)
    [XIAO-nRF52840 v15.step]
2026-02-13 add alternative pin header model
    [PinHeader_2.54mm_2x-12.step]
2026-02-14 tried to fix bug with pcb model merging
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2026-02-15 Fixed mounting hole positions for chocv2
    [config.yaml]
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2026-02-15 Added basic m2 standoff models
    [m2-standoff-10mm.stl, m2-standoff-1mm.stl, m2-standoff-2mm.stl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]
2026-02-15 add screw step models
    [92000A011_Passivated 18-8 Stainless Steel Pan Head Phillips Screw m2 4mm.STEP, 92000A012_Passivated 18-8 Stainless Steel Pan Head Phillips Screw m2 5mm.STEP, 9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]
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2026-02-16 Fixed 3d models naming and added missing wrls
    [92000A011_Passivated_18-8_Stainless_Steel_Pan_Head_Phillips_Screw_m2_4mm.STEP, 92000A012_Passivated_18-8_Stainless_Steel_Pan_Head_Phillips_Screw_m2_5mm.STEP, 9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]
2026-02-16 Added more 3d models,. changed ergogen config to use them
    [92985A817_Splined Press-Fit_Threaded_Standoffs_with_Open_End_m2_onesided_standoff 2mm.STEP, 92985A818_Splined_Press-Fit_Threaded_Standoffs_with_Open_End_m2_one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]
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2026-02-16 Added some missing elements to filtered output
    [l_3d_preview.stl, l_case_3d.stl, l_cover.stl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]
2026-02-16 Added more missing elements to filtered output
    [l_all_key_clusters_outline.dxf, l_case_border.dxf, l_case_border_do_not_ocupy.dxf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]
2026-02-16 Finally fixed pcb and pcb components rotation
2026-03-07 Added 3d models for the m1.4 and m.16 screws
    [M1.4 2mm flat head 91800A713_18-8 Stainless Steel Cheese Head Slotted Screw.STEP, M1.4 3mm flat head 91800A030_18-8 Stainless Steel Cheese Head Slotted Screw.S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]
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2026-03-08 Multiple comits with the goal of fixing 3d model preview
    [config.yaml]
